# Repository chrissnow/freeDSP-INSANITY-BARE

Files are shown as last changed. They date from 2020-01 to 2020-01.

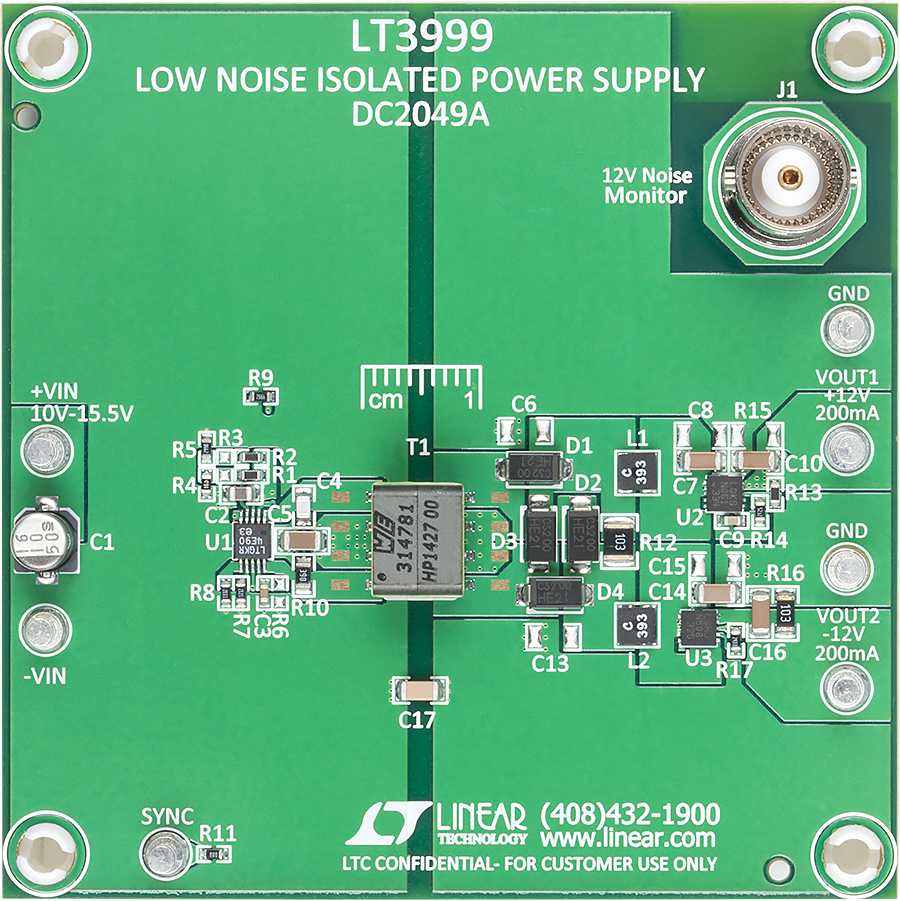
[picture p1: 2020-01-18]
KNOWLEDGE/20170114_LT3999_Example_Circuit_DC2049A_Board.png

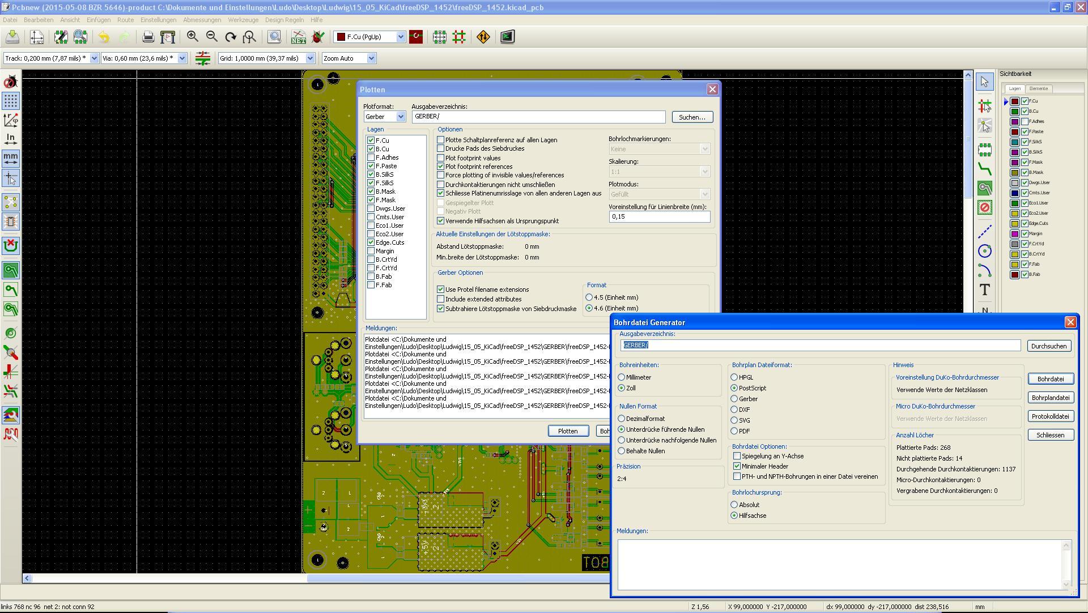
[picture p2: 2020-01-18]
GERBER/GERBER_Settings_Export1.JPG

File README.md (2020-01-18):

# freeDSP INSANITY BARE

BOARD STATUS: WORK IN PROGRESS - DO NOT BUILD!

MAIN COORDINATOR: [sudlud](https://github.com/sudlud), [blauespferd](https://github.com/blauespferd)

Working directory for the modularized freeDSP INSANITY (the big brother of freeDSP classic). (Final board-name still undefined)

LIBRARY:

This project uses the freeDSP-KiCad-Library:
https://github.com/freeDSP/freeDSP-KiCadLibrary.git

The library is included as a submodule. It can be initialized using the following commands:

git submodule init

git submodule update

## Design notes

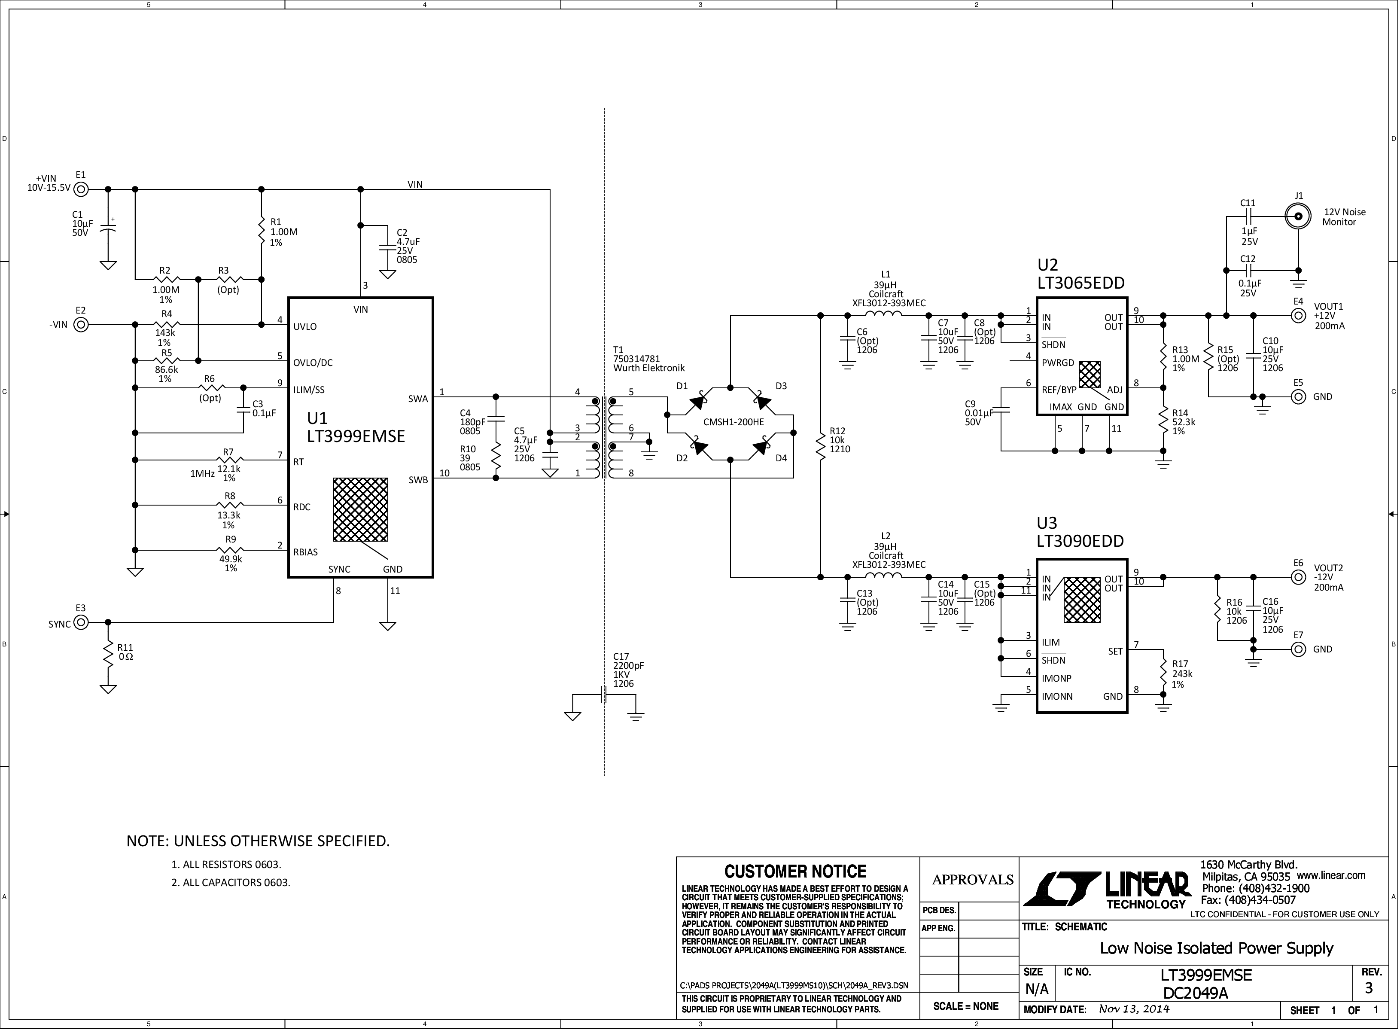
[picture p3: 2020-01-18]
KNOWLEDGE/20170114_LT3999_Example_Circuit_DC2049A.png

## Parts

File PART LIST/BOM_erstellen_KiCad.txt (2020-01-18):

BOM-Export über PCBNEW

-> Datei -> Feritungsdaten erstellen -> BOM-Datei !!! Viel besser als die BOM aus EESCHEMA

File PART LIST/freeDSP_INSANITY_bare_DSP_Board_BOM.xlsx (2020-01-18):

ID | Bezeichner | Geh√§use | St√ºckzahl | Bezeichnung | Anbieter und Referenz | Reichelt.de | DigiKey.com | Conrad.de
1 | C4,C1,C133,C130,C129,C121,C119,C110,C109,C105,C100,C93,C91 | C_0805 | 13 | 10u |  | X5R-G0805 10/16
2 | FB5,FB4,FB3,FB2 | R_0603 | 4 | BLM18PG471SN1 |  | BLM18PG 471
3 | C7,C6,C5,C3,C2,C134,C132,C131,C128,C127,C118,C117,C114,C113,C112,C111,C107,C103,C101,C98,C97,C95,C92,C88 | C_0603 | 24 | 100n |  | X7R-G0603 100N
4 | U1 | TSSOP-24_4.4x7.8mm_P0.65mm | 1 | W232-10-fdsp_digital |  |  | 428-2893-5-ND
5 | R6,R5,R4,R3,R2,R1 | R_0603_Solderjumper_Closed | 6 | Jumper_NC_Small
6 | REF**,REF**,REF**,REF** | MountingHole_3.2mm_M3 | 4 | MountingHole_3.2mm_M3
7 | P5,P4,P3,P2,P1,P33,P30,P27 | IDC_Header_Straight_16pins | 8 | CONN_02X08 |  | WSL 16G
8 | U16 | SOIJ-8_5.3x5.3mm_Pitch1.27mm | 1 | 25AA1024 |  |  | 25AA1024-I/SM-ND
9 | P24 | IDC_Header_Straight_10pins | 1 | CONN_02X05 |  | WSL 10G
10 | P28 | FC684205T_R | 1 | FC684205R |  |  |  | 457611
11 | P25 | FC684205T_R | 1 | FC684205T
12 | U17 | CB3LV-3C-24M5760 | 1 | CB3LV-3C-24M5760 |  |  | CTX1269CT-ND
13 | U13 | SOT23-6_1.7x3.0mm_Pitch0.95mm | 1 | LM2842Y |  |  | LM2842YMK-ADJL/NOPBCT-ND
14 | U12 | LFCSP-72_10x10mm_Pitch0.5mm_ADAU1452 | 1 | ADAU1452 |  |  | ADAU1452WBCPZ-ND
15 | SW1 | SW_SPST_PTS645 | 1 | SW_PUSH_SMALL |  | TASTER 9315
16 | R163,R161,R159,R156,R123,R121 | R_0603 | 6 | 10k |  | SMD-0603 10K
17 | R162,R160,R148,R147,R132,R122 | R_0603 | 6 | 1k |  | SMD-0603 1,0K
18 | R158,R157 | R_0603_Solderjumper_Open | 2 | 10k
19 | R155,R154 | R_0603_Solderjumper_Open | 2 | 0
20 | R151 | R_0603 | 1 | 3.4k |  | RND 0603 1 3,4K
21 | R149 | R_0603 | 1 | 1.02k |  |  | 311-1.02KHRCT-ND
22 | R146,R145,R144,R143,R142,R141,R140,R139,R138,R137,R136,R135,R131,R130,R129,R128,R127,R126,R125,R124 | R_0603 | 20 | 33 |  | SMD-0603 33
23 | R134 | R_0603 | 1 | 50 |  | SMD-0603 47
24 | R133 | R_0603 | 1 | 4.3k |  | RND 0603 1 4,3K
25 | Q1 | D-Pak_TO252AA | 1 | STD2805T4 |  |  | 497-7465-1-ND
26 | P42 | Pin_Header_Straight_2x08 | 1 | CONN_02X08 |  | MPE 087-2-016
27 | P41 | Pin_Header_Straight_2x06 | 1 | CONN_02X06 |  | MPE 087-2-016 (gekürzt)
28 | P40,P39,P38,P37,P36,P35,P31,P26,P23,P18,P17,P15 | Measurement_Point_Round-SMD-Pad_Small | 12 | TST
29 | P34 | Pin_Header_Straight_1x08 | 1 | CONN_01X08 |  | MPE 087-1-008
30 | P16 | RIACON101-2 | 1 | CONN_01X02 |  | AKL 101-02
31 | L1 | Choke_SMD_6.0x5.8 | 1 | 47u |  | L-PIS2408 47µ
32 | JP1 | Pin_Header_Straight_1x02 | 1 | Jumper_NO_Small |  | MPE 087-1-002
33 | FB1 | R_1206 | 1 | Ferrite bead |  |  | 240-2405-1-ND
34 | F1 | R_1206 | 1 | 0ZCJ0050AF2E |  |  | 507-1803-1-ND
35 | D6,D2 | SMA | 2 | B150 |  |  | B150-FDICT-ND
36 | D5 | SMA | 1 | SMAJ28A |  | SMAJ 15A VIS
37 | D4,D3 | R_0603 | 2 | green |  | SMD-LED 0603 GN
38 | C115 | C_0805 | 1 | 150n |  | X7R 0805FCF 150N
39 | C104 | CP_Elec_10x10.5 | 1 | 100u |  | VF 100/63 K-G
40 | C102,C99,C96,C94 | C_0603 | 4 | 1u |  | X5R-G0603 1,0/25
41 | C90 | C_0603 | 1 | 150p |  | NPO-G0603 150P
42 | C89 | C_0805 | 1 | 5.6n |  | X7R 0805 CF 5,6N

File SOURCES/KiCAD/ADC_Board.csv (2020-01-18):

ID | Bezeichner | Gehäuse | Stückzahl | Bezeichnung | Anbieter und Referenz
1 | C33,C37,C38,C39,C40,C41,C42,C43,C55,C56,C57,C58,C59,C60,C61,C62 | C_Radial_D5_L11_P2.5 | 16 | 10u
2 | C44,C64 | C_0603 | 2 | 1u
3 | C45,C46,C54,C68,C69,C76,C81,C82,C83,C86,C91,C92 | C_0603 | 12 | 100n
4 | C47,C53,C70,C75,C84 | C_0805 | 5 | 10u
5 | C48,C49,C50,C51,C71,C72,C73,C74 | C_1206 | 8 | 1.5n
6 | C77,C78,C79,C80,C87,C88,C89,C90 | C_Radial_D10_L16_P5 | 8 | 22u
7 | D8 | SOT-23 | 1 | LM4040DYM3-2.5
8 | J1,J2 | AUDIO_JACK_STEREO_12PIN_FCR1117 | 2 | AUDIO_JACK_STEREO_12PIN_FCR1117
9 | P4,P5,P6,P7,P14,P15 | Measurement_Point_Round-SMD-Pad_Small | 6 | TST
10 | R37,R38,R39,R40,R41,R42,R43,R44,R57,R58,R59,R60,R61,R62,R63,R64 | R_0603 | 16 | 330
11 | R45,R47,R52,R54,R55,R65,R67,R72,R74,R75 | R_0603_Solderjumper_Open | 10 | Jumper_NO_Small
12 | R46,R48,R51,R53,R56,R66,R68,R71,R73,R76 | R_0603_Solderjumper_Closed | 10 | Jumper_NC_Small
13 | R49,R69,R77,R78,R79,R80,R99,R100,R101,R102,R103 | R_0603 | 11 | 10k
14 | R50,R70 | R_0603 | 2 | 33
15 | R87,R88,R89,R90,R104,R105,R106,R107 | R_0603 | 8 | 8.06k
16 | R91,R92,R93,R94,R95,R96,R97,R98,R108,R109,R110,R112,R113,R114,R115,R116 | R_0603 | 16 | 4.7k
17 | U5,U6 | SSOP-28_5.3x10.2mm_Pitch0.65mm | 2 | AK5384
18 | U7,U8,U11,U12 | TSSOP-16_4.4x5mm_Pitch0.65mm | 4 | OPA4353
19 | U9 | SOIC-8_3.9x4.9mm_Pitch1.27mm | 1 | OPA337

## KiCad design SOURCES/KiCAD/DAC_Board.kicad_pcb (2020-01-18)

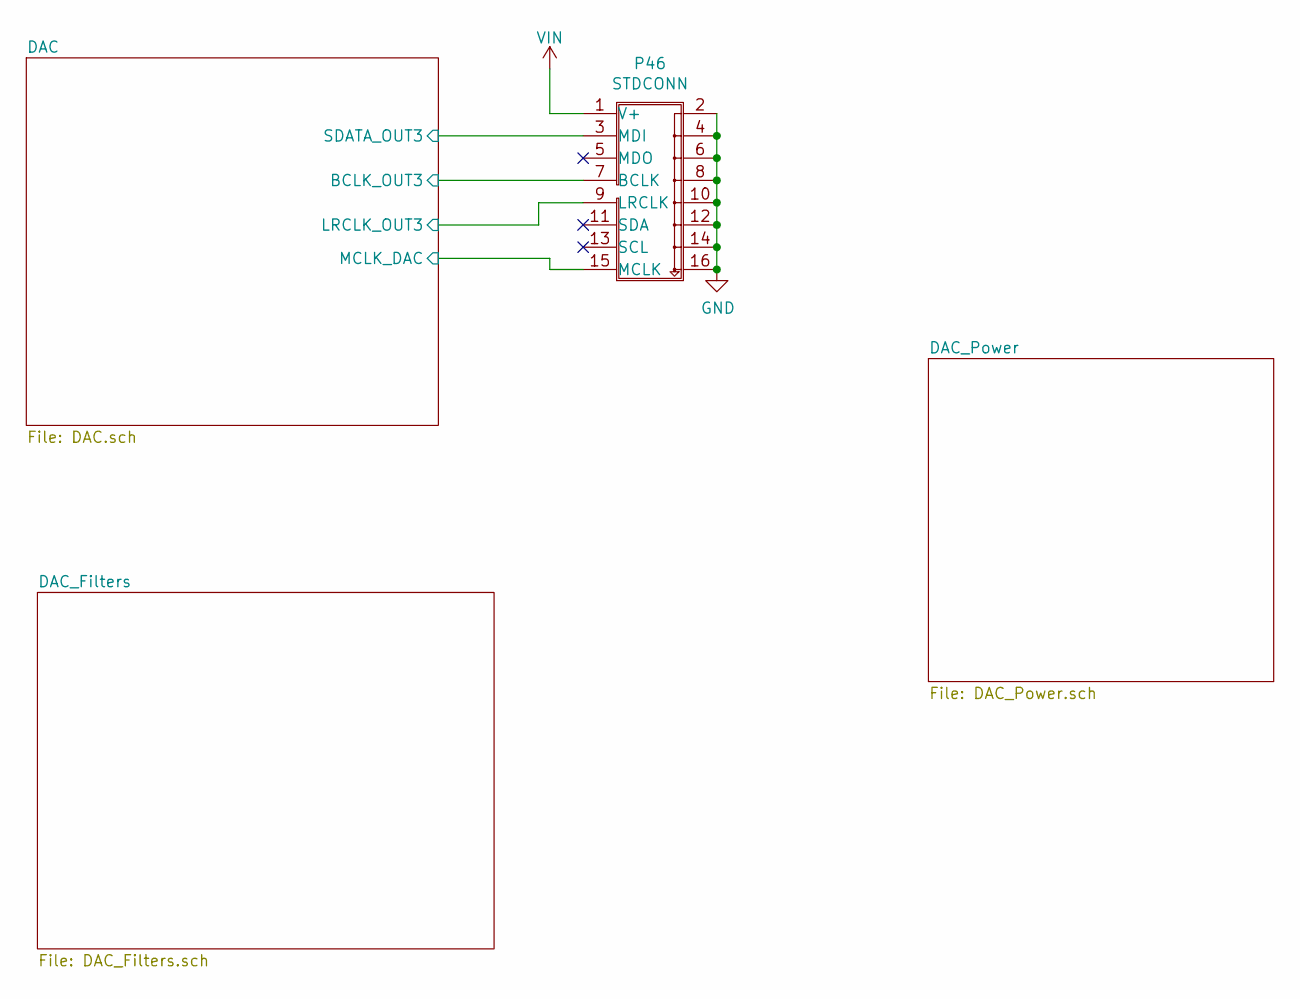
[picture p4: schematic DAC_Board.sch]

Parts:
P46: STDCONN; IDC_Header_Straight_16pins

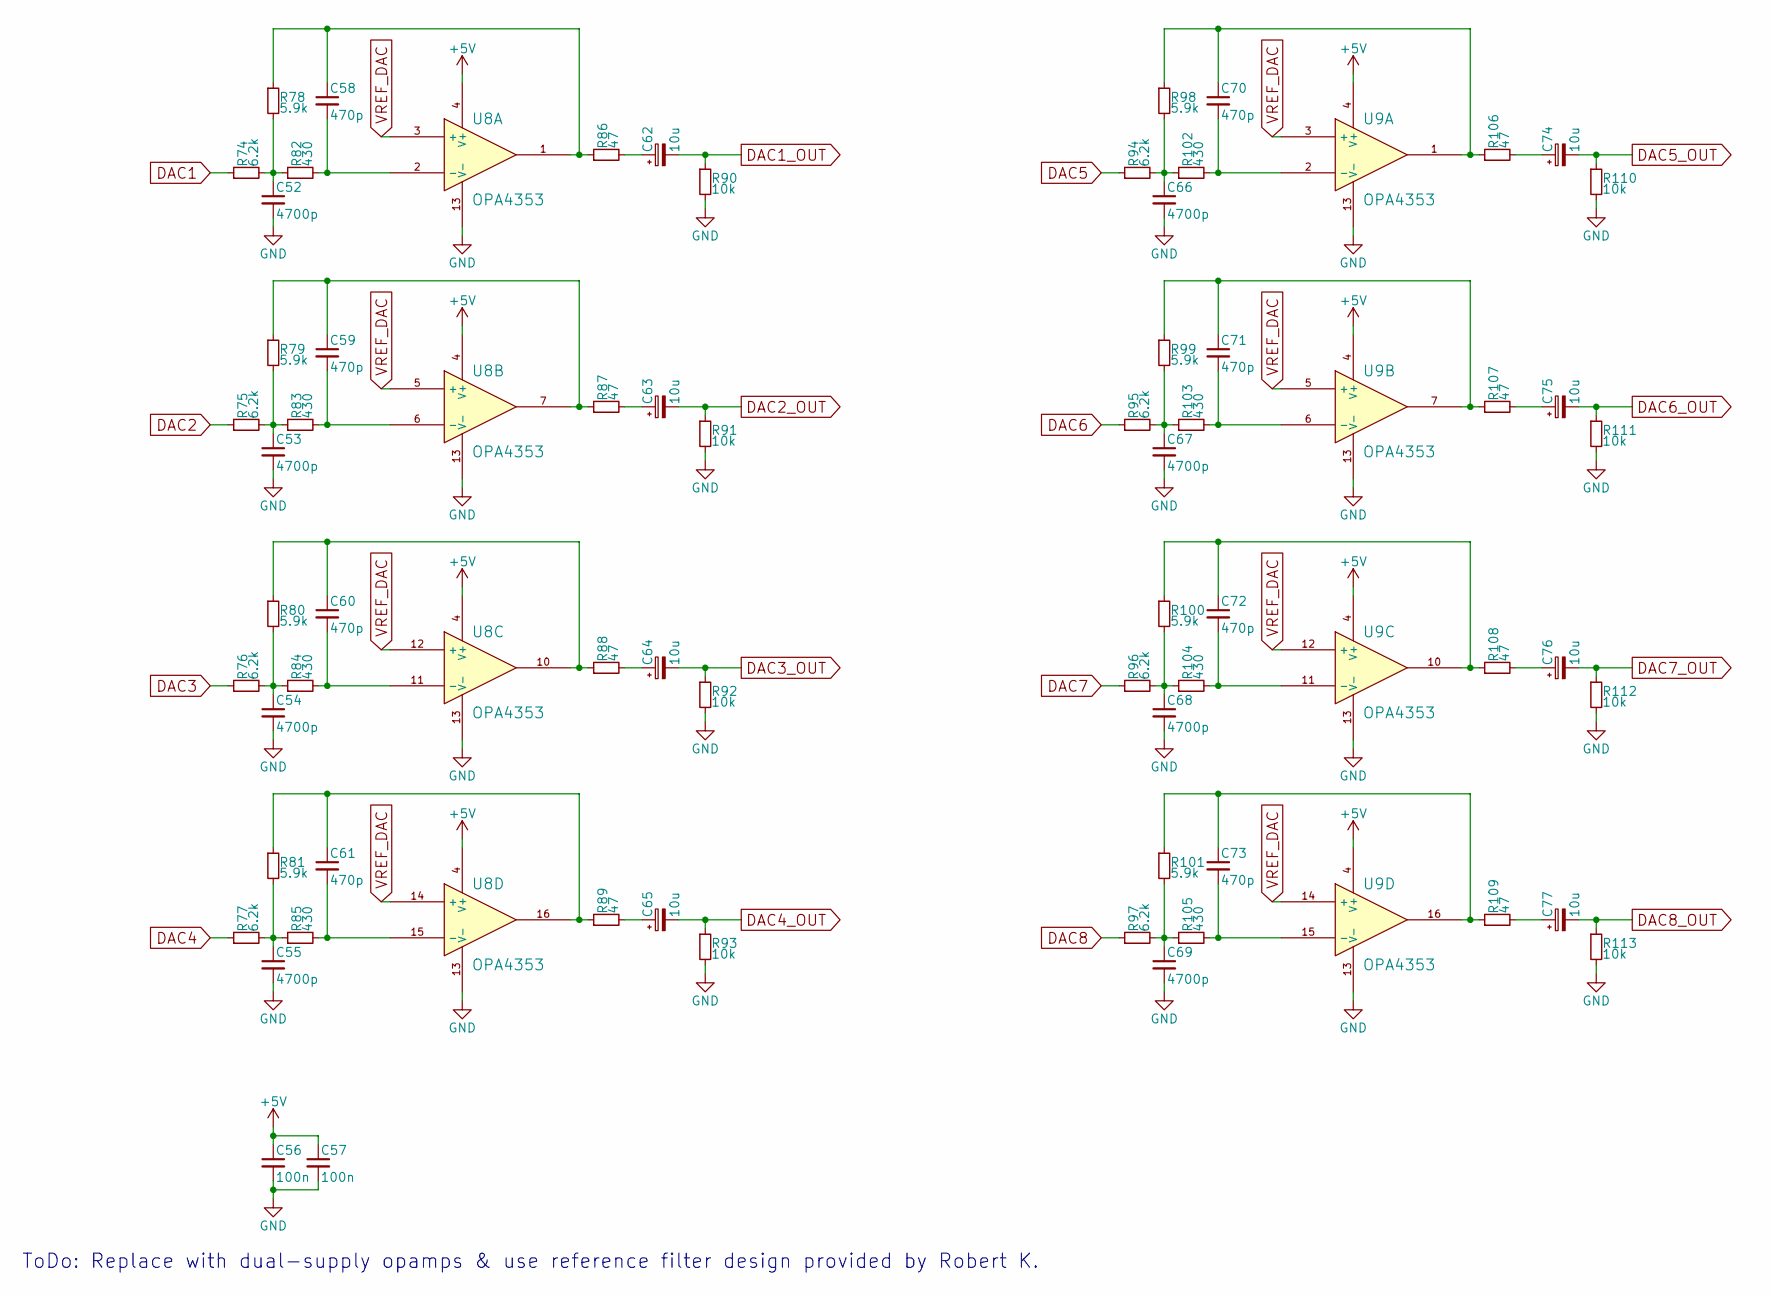
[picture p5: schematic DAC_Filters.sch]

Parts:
C52, C53, C54, C55, C66, C67, C68, C69: 4700p; C_1206
C56, C57: 100n; C_0603
C58, C59, C60, C61, C70, C71, C72, C73: 470p; C_1206
C62, C63, C64, C65, C74, C75, C76, C77: 10u; C_Radial_D10_L16_P5
R74, R75, R76, R77, R94, R95, R96, R97: 6.2k; R_0603
R78, R79, R80, R81, R98, R99, R100, R101: 5.9k; R_0603
R82, R83, R84, R85, R102, R103, R104, R105: 430; R_0603
R86, R87, R88, R89, R106, R107, R108, R109: 47; R_0603
R90, R91, R92, R93, R110, R111, R112, R113: 10k; R_0603
U8, U9: OPA4353; TSSOP-16_4.4x5mm_Pitch0.65mm

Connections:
+5V: C56.1, C57.1, U8.4 (V+), U9.4 (V+); also elsewhere on the board
DAC1: R74.1; also elsewhere on the board
DAC1_OUT: C62.2, R90.1; also elsewhere on the board
DAC2: R75.1; also elsewhere on the board
DAC2_OUT: C63.2, R91.1; also elsewhere on the board
DAC3: R76.1; also elsewhere on the board
DAC3_OUT: C64.2, R92.1; also elsewhere on the board
DAC4: R77.1; also elsewhere on the board
DAC4_OUT: C65.2, R93.1; also elsewhere on the board
DAC5: R94.1; also elsewhere on the board
DAC5_OUT: C74.2, R110.1; also elsewhere on the board
DAC6: R95.1; also elsewhere on the board
DAC6_OUT: C75.2, R111.1; also elsewhere on the board
DAC7: R96.1; also elsewhere on the board
DAC7_OUT: C76.2, R112.1; also elsewhere on the board
DAC8: R97.1; also elsewhere on the board
DAC8_OUT: C77.2, R113.1; also elsewhere on the board
GND: C52.2, C53.2, C54.2, C55.2, C56.2, C57.2, C66.2, C67.2, C68.2, C69.2, R90.2, R91.2, R92.2, R93.2, R110.2, R111.2, R112.2, R113.2, U8.13 (V-), U9.13 (V-); also elsewhere on the board
unnamed: C52.1, R74.2, R78.2, R82.1
unnamed: C53.1, R75.2, R79.2, R83.1
unnamed: C54.1, R76.2, R80.2, R84.1
unnamed: C55.1, R77.2, R81.2, R85.1
unnamed: C58.1, R78.1, R86.1, U8.1
unnamed: C58.2, R82.2, U8.2 (-)
unnamed: C59.1, R79.1, R87.1, U8.7
unnamed: C59.2, R83.2, U8.6 (-)
unnamed: C60.1, R80.1, R88.1, U8.10
unnamed: C60.2, R84.2, U8.11 (-)
unnamed: C61.1, R81.1, R89.1, U8.16
unnamed: C61.2, R85.2, U8.15 (-)
unnamed: C62.1, R86.2
unnamed: C63.1, R87.2
unnamed: C64.1, R88.2
unnamed: C65.1, R89.2
unnamed: C66.1, R94.2, R98.2, R102.1
unnamed: C67.1, R95.2, R99.2, R103.1
unnamed: C68.1, R96.2, R100.2, R104.1
unnamed: C69.1, R97.2, R101.2, R105.1
unnamed: C70.1, R98.1, R106.1, U9.1
unnamed: C70.2, R102.2, U9.2 (-)
unnamed: C71.1, R99.1, R107.1, U9.7
unnamed: C71.2, R103.2, U9.6 (-)
unnamed: C72.1, R100.1, R108.1, U9.10
unnamed: C72.2, R104.2, U9.11 (-)
unnamed: C73.1, R101.1, R109.1, U9.16
unnamed: C73.2, R105.2, U9.15 (-)
unnamed: C74.1, R106.2
unnamed: C75.1, R107.2
unnamed: C76.1, R108.2
unnamed: C77.1, R109.2
VREF_DAC: U8.3 (+), U8.5 (+), U8.12 (+), U8.14 (+), U9.3 (+), U9.5 (+), U9.12 (+), U9.14 (+); also elsewhere on the board

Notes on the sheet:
ToDo: Replace with dual-supply opamps & use reference filter design provided by Robert K.

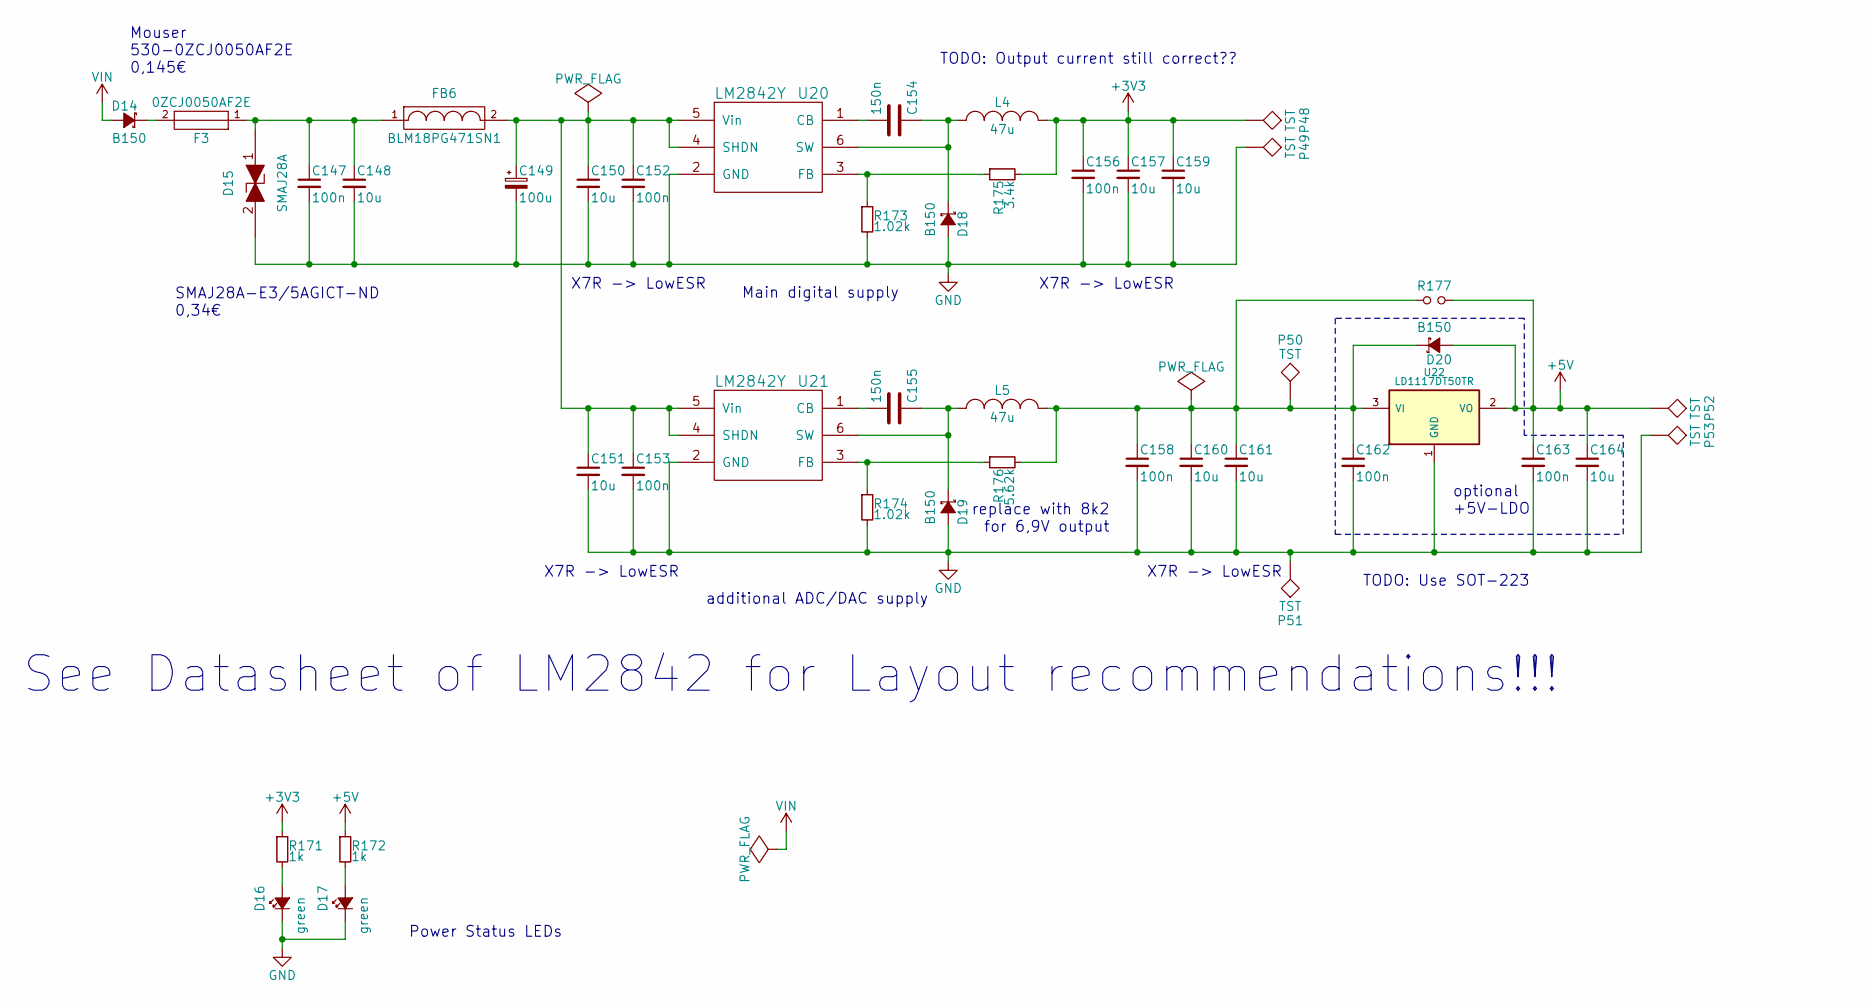
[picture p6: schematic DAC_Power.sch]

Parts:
C147, C152, C153, C156, C158, C162, C163: 100n; C_0603
C148, C150, C151, C157, C159, C160, C161, C164: 10u; C_0805
C149: 100u; CP_Elec_10x10.5
C154, C155: 150n; C_0805
D14, D18, D19, D20: B150; SMA
D15: SMAJ28A; SMA; Digikey_Paro_No SMAJ28A-E3/5AGICT-ND
D16, D17: green; R_0603
F3: 0ZCJ0050AF2E; R_1206; Mouser_Part_No 530-0ZCJ0050AF2E
FB6: BLM18PG471SN1; R_0603; Mouser_Part_No 81-BLM18PG471SN1D
L4, L5: 47u; Choke_SMD_6.0x5.8
P48, P49, P50, P51, P52, P53: TST; Measurement_Point_Round-SMD-Pad_Small
R171, R172: 1k; R_0603
R173, R174: 1.02k; R_0603
R175: 3.4k; R_0603
R176: 5.62k; R_0603
R177: Jumper_NO_Small; R_0603_Solderjumper_Open
U20, U21: LM2842Y; SOT23-6_1.7x3.0mm_Pitch0.95mm
U22: LD1117DT50TR; SOT-223

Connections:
+3V3: C156.1, C157.1, C159.1, L4.2, P48.1, R171.1, R175.2; also elsewhere on the board
+5V: C163.1, C164.1, D20.2 (A), P52.1, R172.1, R177.2, U22.2 (VO); also elsewhere on the board
GND: C147.2, C148.2, C149.2, C150.2, C151.2, C152.2, C153.2, C156.2, C157.2, C158.2, C159.2, C160.2, C161.2, C162.2, C163.2, C164.2, D15.2, D16.1 (K), D17.1 (K), D18.2 (A), D19.2 (A), P49.1, P51.1, P53.1, R173.2, R174.2, U20.2 (GND), U21.2 (GND), U22.1 (GND); also elsewhere on the board
unnamed: C147.1, C148.1, D15.1, F3.1, FB6.1
unnamed: C149.1, C150.1, C151.1, C152.1, C153.1, FB6.2, U20.4 (SHDN), U20.5 (Vin), U21.4 (SHDN), U21.5 (Vin)
unnamed: C154.1, D18.1 (K), L4.1, U20.6 (SW)
unnamed: C154.2, U20.1 (CB)
unnamed: C155.1, D19.1 (K), L5.1, U21.6 (SW)
unnamed: C155.2, U21.1 (CB)
unnamed: C158.1, C160.1, C161.1, C162.1, D20.1 (K), L5.2, P50.1, R176.2, R177.1, U22.3 (VI)
unnamed: D14.1 (K), F3.2
unnamed: D16.2 (A), R171.2
unnamed: D17.2 (A), R172.2
unnamed: R173.1, R175.1, U20.3 (FB)
unnamed: R174.1, R176.1, U21.3 (FB)
VIN: D14.2 (A); also elsewhere on the board

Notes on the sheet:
Power Status LEDs
Main digital supply
additional ADC/DAC supply
X7R -> LowESR
See Datasheet of LM2842 for Layout recommendations!!!
replace with 8k2 for 6,9V output
optional +5V-LDO
Mouser 530-0ZCJ0050AF2E 0,145€
TODO: Use SOT-223
TODO: Output current still correct??
SMAJ28A-E3/5AGICT-ND 0,34€

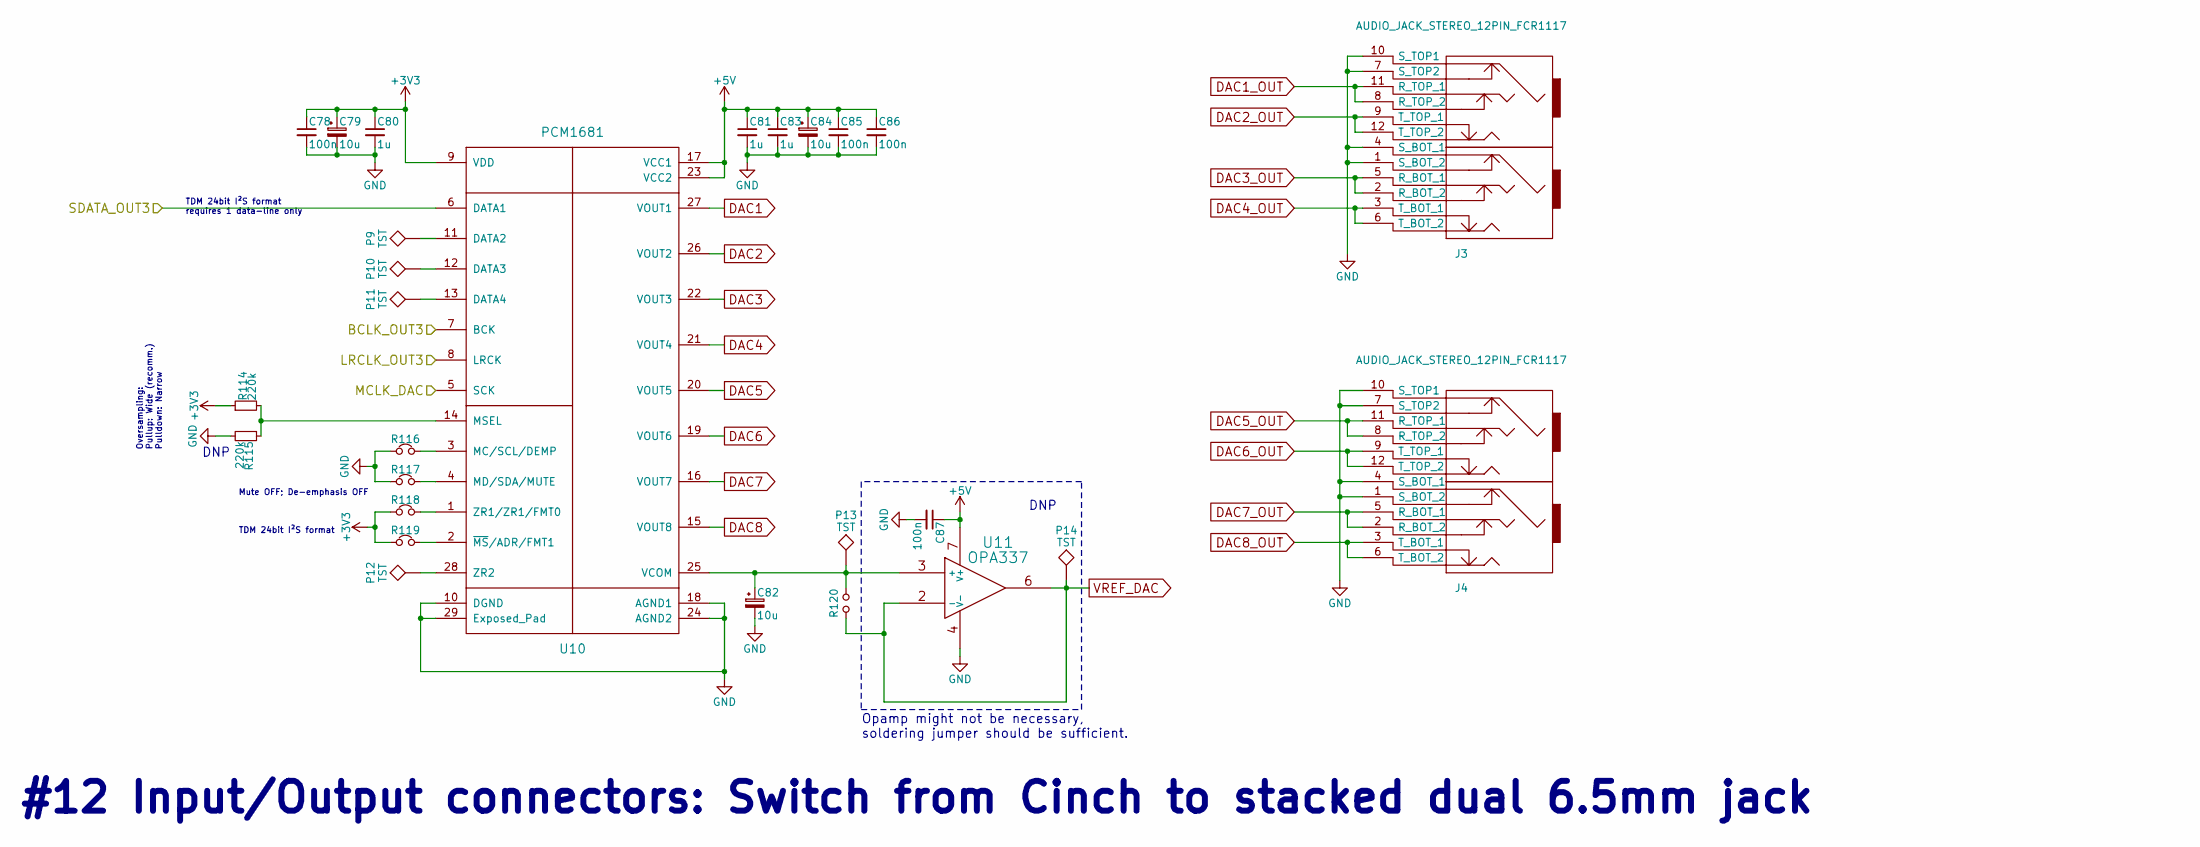
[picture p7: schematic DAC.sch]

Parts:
C78, C85, C86, C87: 100n; C_0603
C79, C82, C84: 10u; C_0805
C80, C81, C83: 1u; C_0603
J3, J4: AUDIO_JACK_STEREO_12PIN_FCR1117
P9, P10, P11, P12, P13, P14: TST; Measurement_Point_Round-SMD-Pad_Small
R114, R115: 220k; R_0603
R116, R117, R118, R119: Jumper_NC_Small; R_0603_Solderjumper_Closed
R120: Jumper_NO_Small; R_0603_Solderjumper_Open
U10: PCM1681; TSSOP-28_10x5mm_Pitch0.65mm_PCM1681
U11: OPA337; SOIC-8_3.9x4.9mm_Pitch1.27mm

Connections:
+3V3: C78.1, C79.1, C80.1, R114.1, R118.1, R119.1, U10.9 (VDD); also elsewhere on the board
+5V: C81.1, C83.1, C84.1, C85.1, C86.1, C87.1, U10.17 (VCC1), U10.23 (VCC2), U11.7 (V+); also elsewhere on the board
/DAC/BCLK_OUT3: U10.7 (BCK); also elsewhere on the board
/DAC/LRCLK_OUT3: U10.8 (LRCK); also elsewhere on the board
/DAC/MCLK_DAC: U10.5 (SCK); also elsewhere on the board
/DAC/SDATA_OUT3: U10.6 (DATA1); also elsewhere on the board
DAC1: U10.27 (VOUT1); also elsewhere on the board
DAC1_OUT: J3.8 (R_TOP_2), J3.11 (R_TOP_1); also elsewhere on the board
DAC2: U10.26 (VOUT2); also elsewhere on the board
DAC2_OUT: J3.9 (T_TOP_1), J3.12 (T_TOP_2); also elsewhere on the board
DAC3: U10.22 (VOUT3); also elsewhere on the board
DAC3_OUT: J3.2 (R_BOT_2), J3.5 (R_BOT_1); also elsewhere on the board
DAC4: U10.21 (VOUT4); also elsewhere on the board
DAC4_OUT: J3.3 (T_BOT_1), J3.6 (T_BOT_2); also elsewhere on the board
DAC5: U10.20 (VOUT5); also elsewhere on the board
DAC5_OUT: J4.8 (R_TOP_2), J4.11 (R_TOP_1); also elsewhere on the board
DAC6: U10.19 (VOUT6); also elsewhere on the board
DAC6_OUT: J4.9 (T_TOP_1), J4.12 (T_TOP_2); also elsewhere on the board
DAC7: U10.16 (VOUT7); also elsewhere on the board
DAC7_OUT: J4.2 (R_BOT_2), J4.5 (R_BOT_1); also elsewhere on the board
DAC8: U10.15 (VOUT8); also elsewhere on the board
DAC8_OUT: J4.3 (T_BOT_1), J4.6 (T_BOT_2); also elsewhere on the board
GND: C78.2, C79.2, C80.2, C81.2, C82.2, C83.2, C84.2, C85.2, C86.2, C87.2, J3.1 (S_BOT_2), J3.4 (S_BOT_1), J3.7 (S_TOP2), J3.10 (S_TOP1), J4.1 (S_BOT_2), J4.4 (S_BOT_1), J4.7 (S_TOP2), J4.10 (S_TOP1), R115.2, R116.1, R117.1, U10.10 (DGND), U10.18 (AGND1), U10.24 (AGND2), U10.29 (Exposed_Pad), U11.4 (V-); also elsewhere on the board
unnamed: C82.1, P13.1, R120.2, U10.25 (VCOM), U11.3 (+)
unnamed: P9.1, U10.11 (DATA2)
unnamed: P10.1, U10.12 (DATA3)
unnamed: P11.1, U10.13 (DATA4)
unnamed: P12.1, U10.28 (ZR2)
unnamed: R114.2, R115.1, U10.14 (MSEL)
unnamed: R116.2, U10.3 (MC/SCL/DEMP)
unnamed: R117.2, U10.4 (MD/SDA/MUTE)
unnamed: R118.2, U10.1 (ZR1/ZR1/FMT0)
unnamed: R119.2, U10.2 (~MS~/ADR/FMT1)
VREF_DAC: P14.1, R120.1, U11.2 (-), U11.6; also elsewhere on the board

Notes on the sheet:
DNP
TDM 24bit I²S format
Mute OFF; De-emphasis OFF
TDM 24bit I²S format requires 1 data-line only
Opamp might not be necessary, soldering jumper should be sufficient.
#12 Input/Output connectors: Switch from Cinch to stacked dual 6.5mm jack
Oversampling: Pullup: Wide (recomm.) Pulldown: Narrow

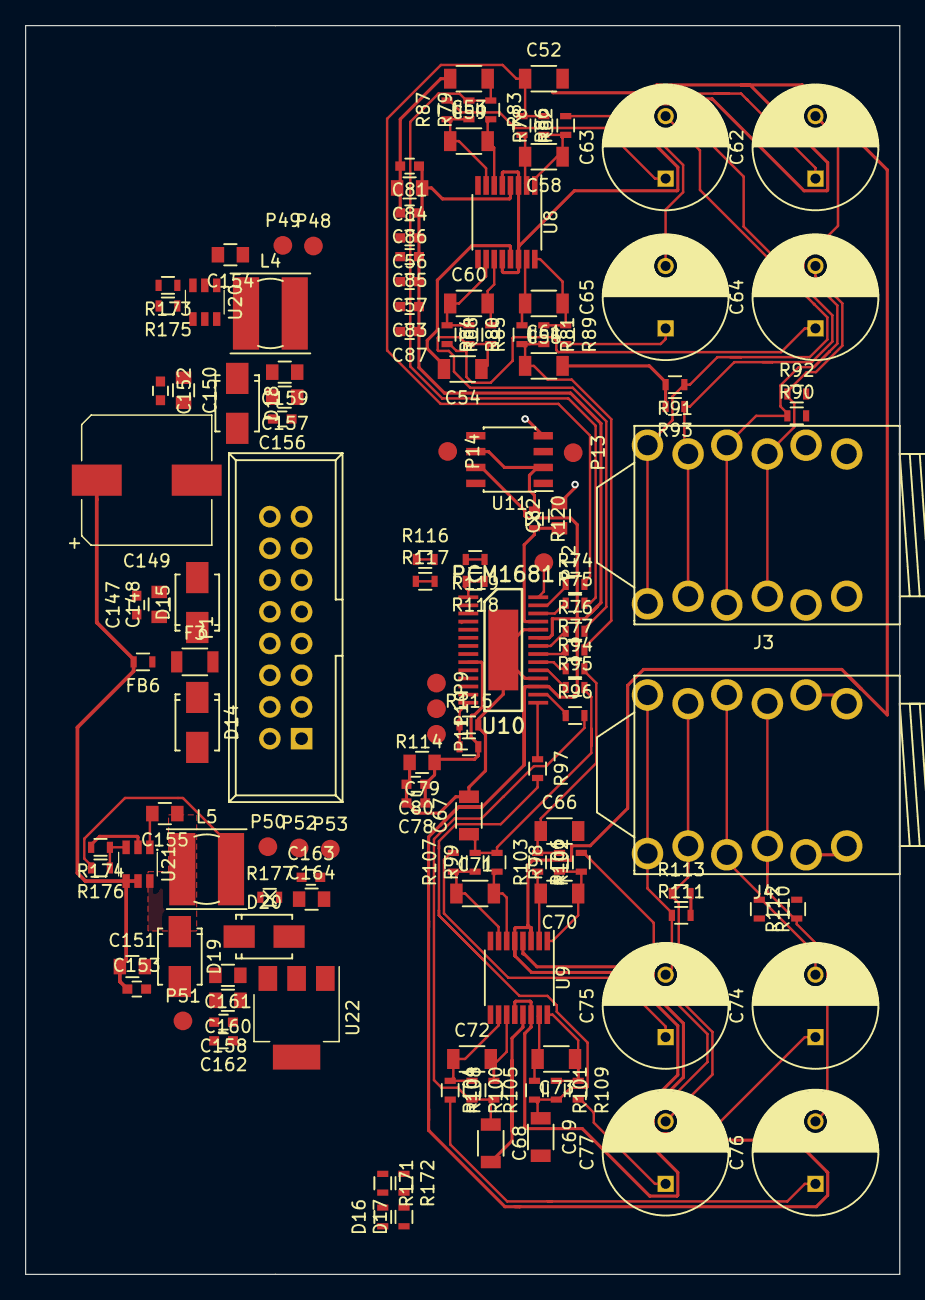
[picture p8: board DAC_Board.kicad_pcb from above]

Board: 2 copper layers, 70.0 x 100.0 mm, 141 parts (0 on the bottom side), 79 nets.

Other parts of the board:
P1: STDCONN; IDC_Header_Straight_16pins

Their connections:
/DAC/BCLK_OUT3: P1.7; also elsewhere on the board
/DAC/LRCLK_OUT3: P1.9; also elsewhere on the board
/DAC/MCLK_DAC: P1.15; also elsewhere on the board
/DAC/SDATA_OUT3: P1.3; also elsewhere on the board
GND: P1.2, P1.4, P1.6, P1.8, P1.10, P1.12, P1.14, P1.16; also elsewhere on the board
VIN: P1.1; also elsewhere on the board

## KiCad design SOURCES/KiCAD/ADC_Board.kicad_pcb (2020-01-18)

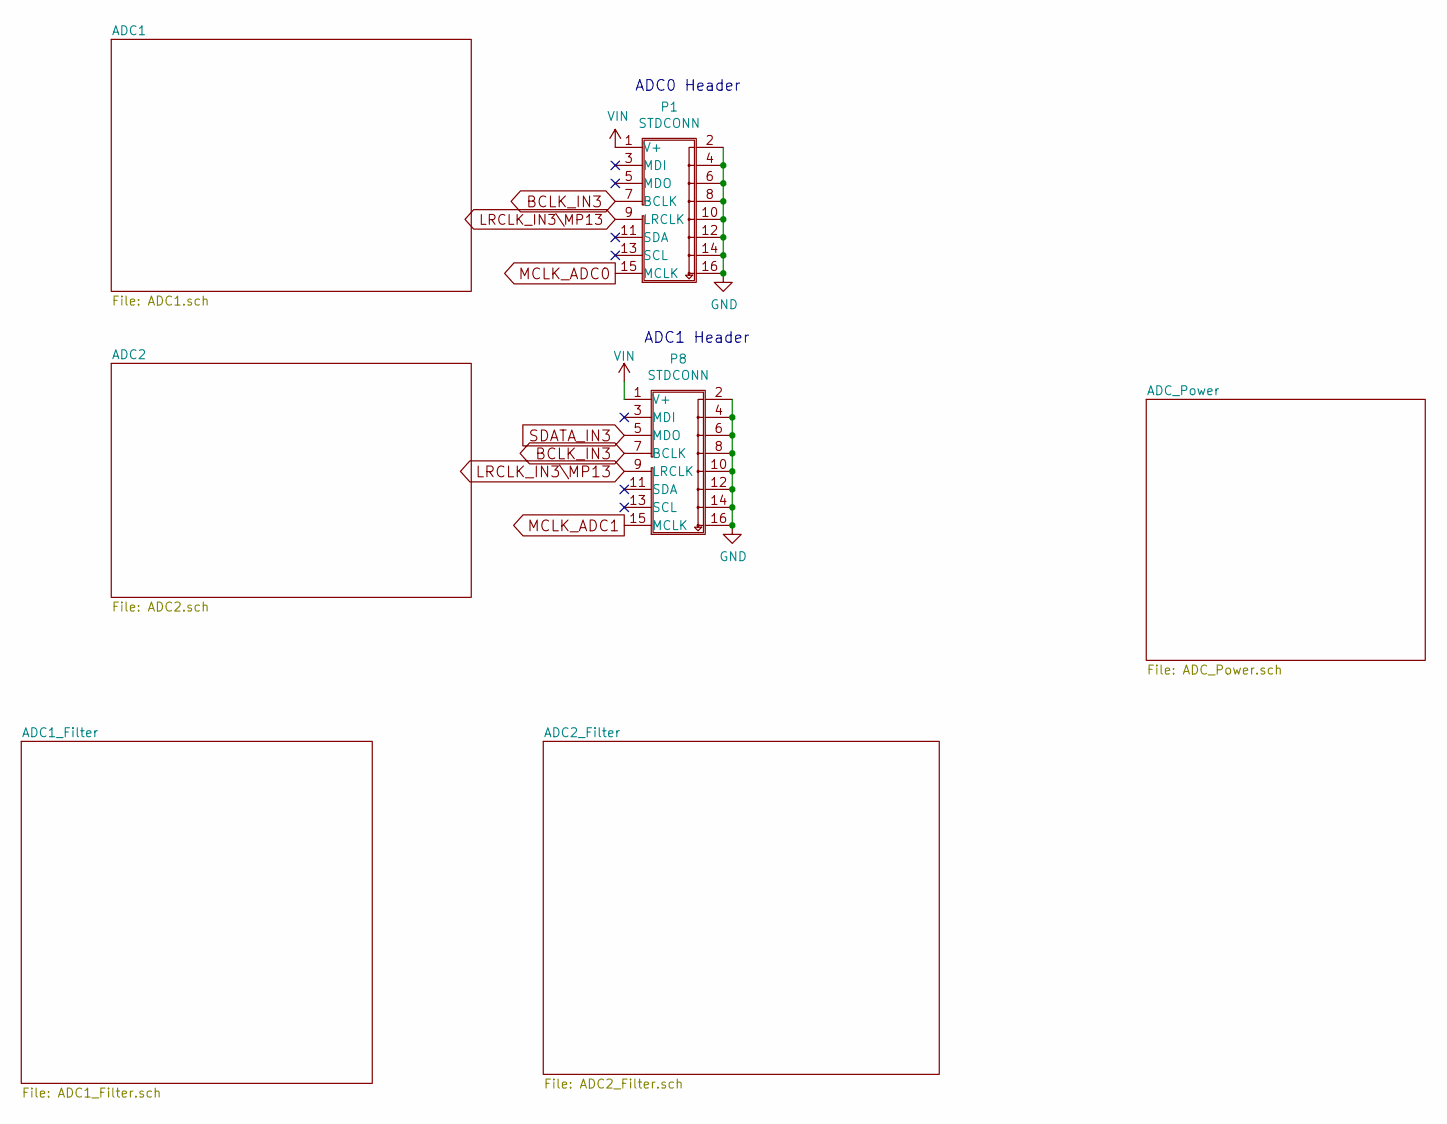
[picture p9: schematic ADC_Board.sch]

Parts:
P1, P8: STDCONN; IDC_Header_Straight_16pins

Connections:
BCLK_IN3: P1.7 (BCLK), P8.7 (BCLK); also elsewhere on the board
GND: P1.2 (GND), P1.4 (GND), P1.6 (GND), P1.8 (GND), P1.10 (GND), P1.12 (GND), P1.14 (GND), P1.16 (GND), P8.2 (GND), P8.4 (GND), P8.6 (GND), P8.8 (GND), P8.10 (GND), P8.12 (GND), P8.14 (GND), P8.16 (GND); also elsewhere on the board
LRCLK_IN3\MP13: P1.9 (LRCLK), P8.9 (LRCLK); also elsewhere on the board
MCLK_ADC0: P1.15 (MCLK); also elsewhere on the board
MCLK_ADC1: P8.15 (MCLK); also elsewhere on the board
SDATA_IN3: P8.5 (MDO); also elsewhere on the board
VIN: P1.1 (V+), P8.1 (V+); also elsewhere on the board

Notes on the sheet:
ADC0 Header
ADC1 Header

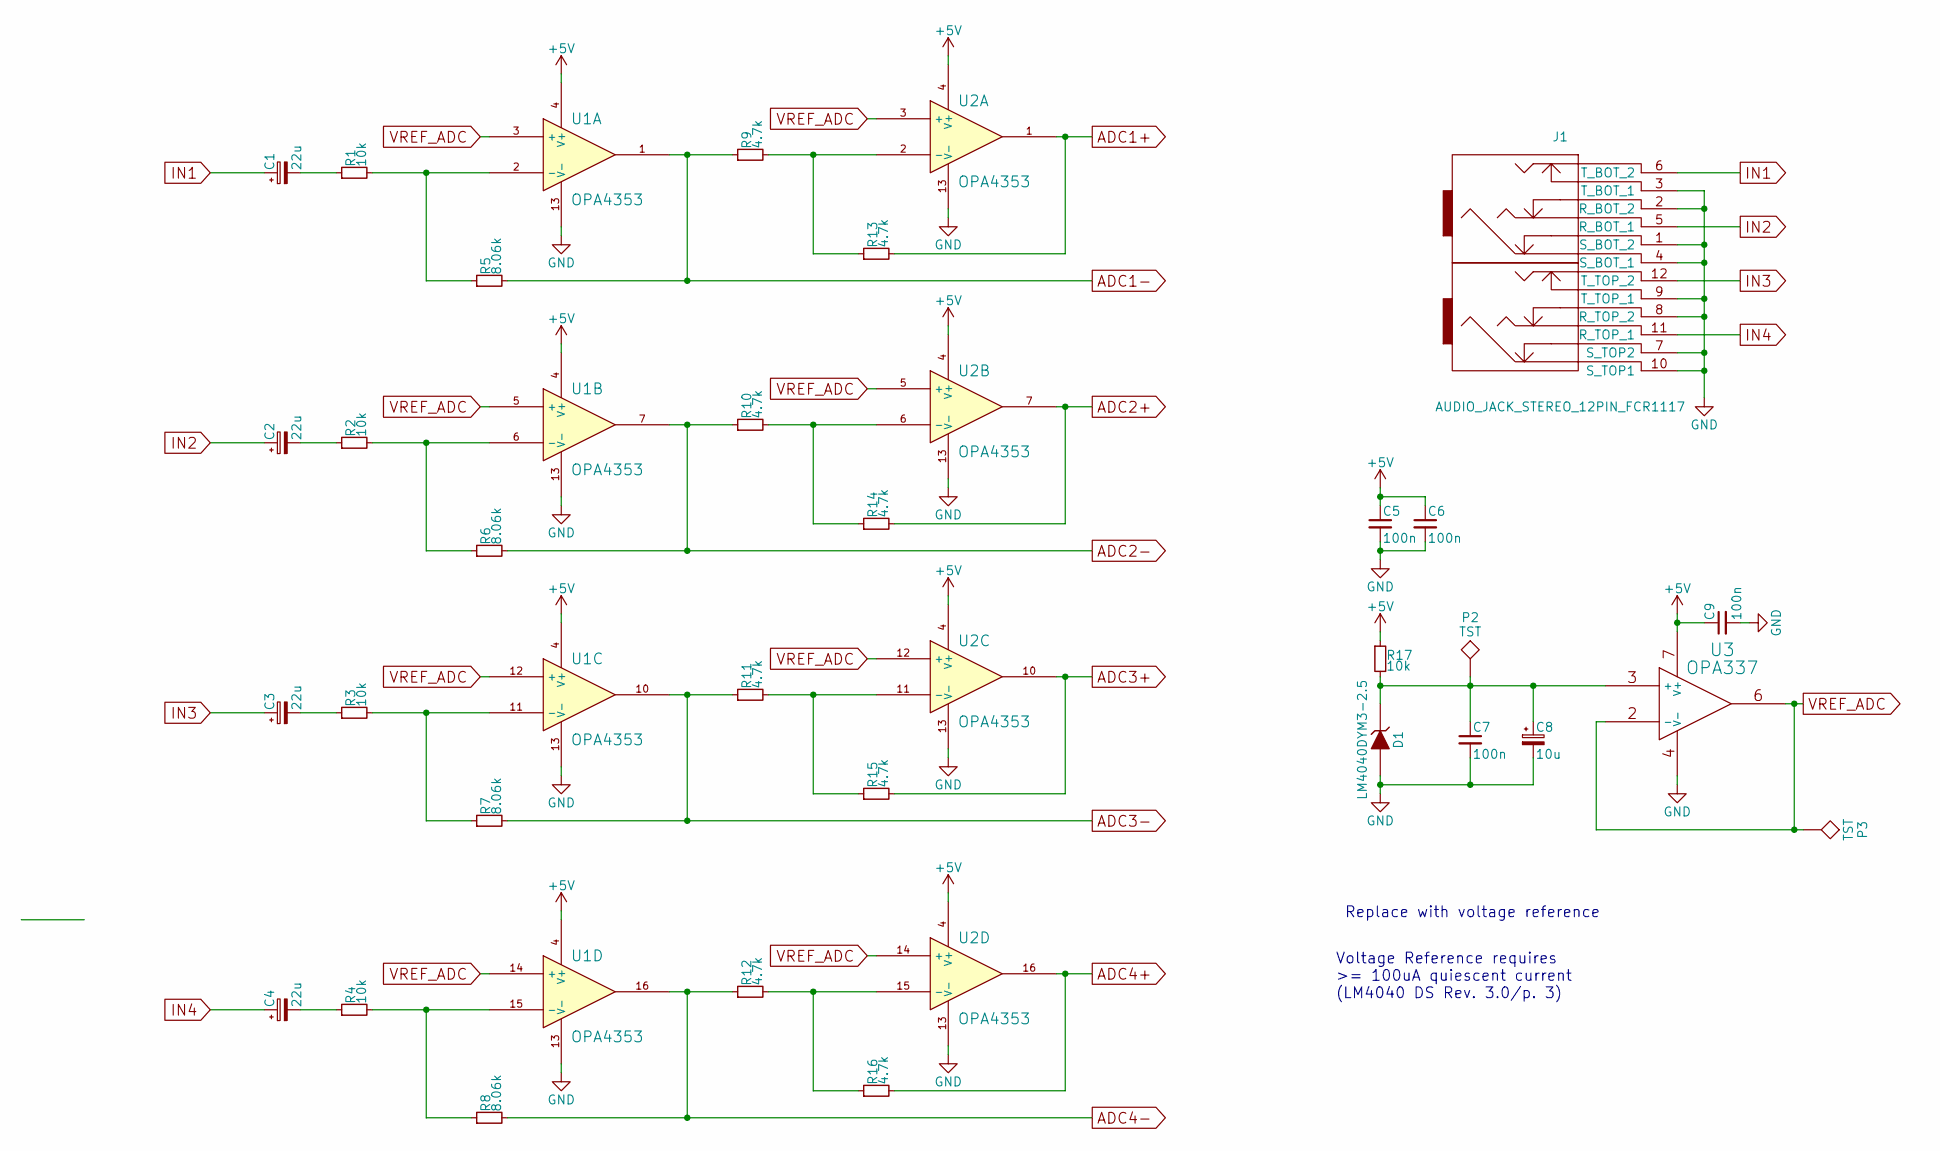
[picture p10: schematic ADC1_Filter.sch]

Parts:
C1, C2, C3, C4: 22u; C_Radial_D10_L16_P5
C5, C6, C7, C9: 100n; C_0603
C8: 10u; C_0805
D1: LM4040DYM3-2.5; SOT-23
J1: AUDIO_JACK_STEREO_12PIN_FCR1117
P2, P3: TST; Measurement_Point_Round-SMD-Pad_Small
R1, R2, R3, R4, R17: 10k; R_0603
R5, R6, R7, R8: 8.06k; R_0603
R9, R10, R11, R12, R13, R14, R15, R16: 4.7k; R_0603
U1, U2: OPA4353; TSSOP-16_4.4x5mm_Pitch0.65mm
U3: OPA337; SOIC-8_3.9x4.9mm_Pitch1.27mm

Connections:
+5V: C5.1, C6.1, C9.1, R17.1, U1.4 (V+), U2.4 (V+), U3.7 (V+); also elsewhere on the board
ADC1+: R13.2, U2.1; also elsewhere on the board
ADC1-: R5.2, R9.1, U1.1; also elsewhere on the board
ADC2+: R14.2, U2.7; also elsewhere on the board
ADC2-: R6.2, R10.1, U1.7; also elsewhere on the board
ADC3+: R15.2, U2.10; also elsewhere on the board
ADC3-: R7.2, R11.1, U1.10; also elsewhere on the board
ADC4+: R16.2, U2.16; also elsewhere on the board
ADC4-: R8.2, R12.1, U1.16; also elsewhere on the board
GND: C5.2, C6.2, C7.2, C8.2, C9.2, D1.2 (A), J1.1 (S_BOT_2), J1.2 (R_BOT_2), J1.3 (T_BOT_1), J1.4 (S_BOT_1), J1.7 (S_TOP2), J1.8 (R_TOP_2), J1.9 (T_TOP_1), J1.10 (S_TOP1), U1.13 (V-), U2.13 (V-), U3.4 (V-); also elsewhere on the board
IN1: C1.1, J1.6 (T_BOT_2)
IN2: C2.1, J1.5 (R_BOT_1)
IN3: C3.1, J1.12 (T_TOP_2)
IN4: C4.1, J1.11 (R_TOP_1)
unnamed: C1.2, R1.1
unnamed: C2.2, R2.1
unnamed: C3.2, R3.1
unnamed: C4.2, R4.1
unnamed: C7.1, C8.1, D1.1 (K), P2.1, R17.2, U3.3 (+)
unnamed: R1.2, R5.1, U1.2 (-)
unnamed: R2.2, R6.1, U1.6 (-)
unnamed: R3.2, R7.1, U1.11 (-)
unnamed: R4.2, R8.1, U1.15 (-)
unnamed: R10.2, R14.1, U2.6 (-)
unnamed: R11.2, R15.1, U2.11 (-)
unnamed: R12.2, R16.1, U2.15 (-)
unnamed: R9.2, R13.1, U2.2 (-)
VREF_ADC: P3.1, U1.3 (+), U1.5 (+), U1.12 (+), U1.14 (+), U2.3 (+), U2.5 (+), U2.12 (+), U2.14 (+), U3.2 (-), U3.6; also elsewhere on the board

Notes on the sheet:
Replace with voltage reference
Voltage Reference requires >= 100uA quiescent current (LM4040 DS Rev. 3.0/p. 3)

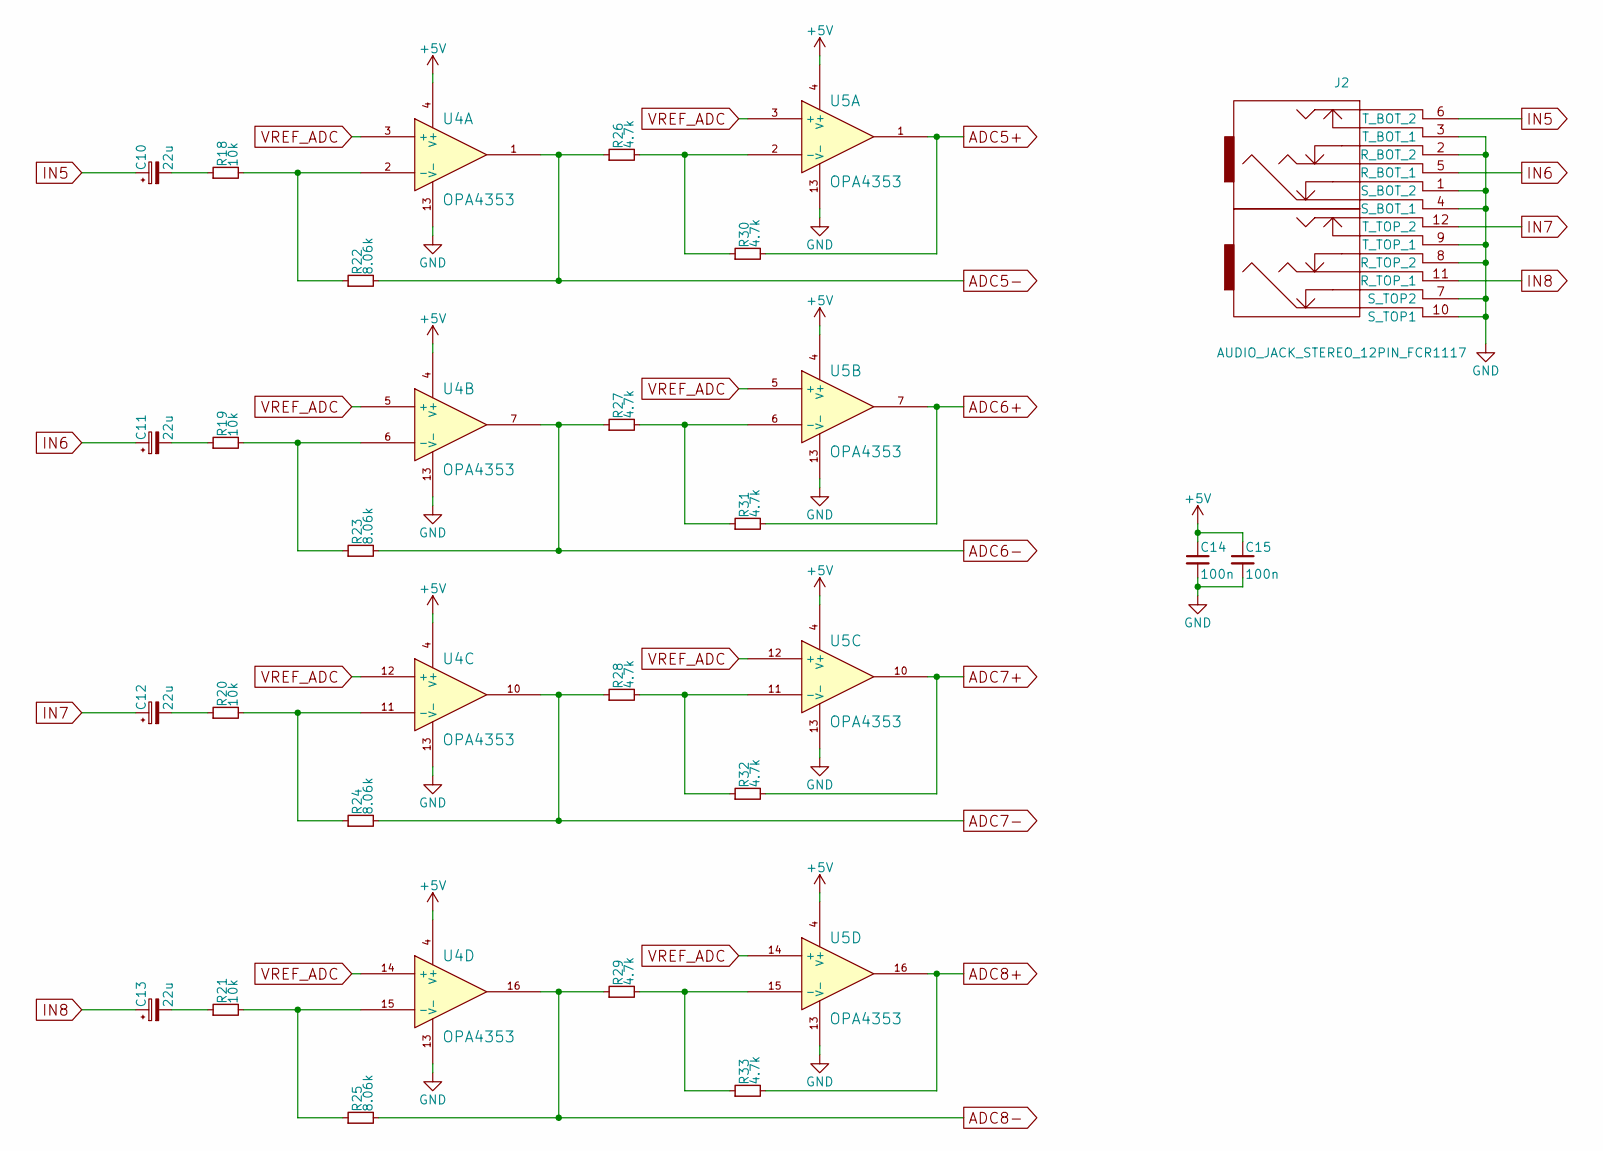
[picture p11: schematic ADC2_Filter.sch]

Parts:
C10, C11, C12, C13: 22u; C_Radial_D10_L16_P5
C14, C15: 100n; C_0603
J2: AUDIO_JACK_STEREO_12PIN_FCR1117
R18, R19, R20, R21: 10k; R_0603
R22, R23, R24, R25: 8.06k; R_0603
R26, R27, R28, R29, R30, R31, R32, R33: 4.7k; R_0603
U4, U5: OPA4353; TSSOP-16_4.4x5mm_Pitch0.65mm

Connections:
+5V: C14.1, C15.1, U4.4 (V+), U5.4 (V+); also elsewhere on the board
ADC5+: R30.2, U5.1; also elsewhere on the board
ADC5-: R22.2, R26.1, U4.1; also elsewhere on the board
ADC6+: R31.2, U5.7; also elsewhere on the board
ADC6-: R23.2, R27.1, U4.7; also elsewhere on the board
ADC7+: R32.2, U5.10; also elsewhere on the board
ADC7-: R24.2, R28.1, U4.10; also elsewhere on the board
ADC8+: R33.2, U5.16; also elsewhere on the board
ADC8-: R25.2, R29.1, U4.16; also elsewhere on the board
GND: C14.2, C15.2, J2.1 (S_BOT_2), J2.2 (R_BOT_2), J2.3 (T_BOT_1), J2.4 (S_BOT_1), J2.7 (S_TOP2), J2.8 (R_TOP_2), J2.9 (T_TOP_1), J2.10 (S_TOP1), U4.13 (V-), U5.13 (V-); also elsewhere on the board
IN5: C10.1, J2.6 (T_BOT_2)
IN6: C11.1, J2.5 (R_BOT_1)
IN7: C12.1, J2.12 (T_TOP_2)
IN8: C13.1, J2.11 (R_TOP_1)
unnamed: C10.2, R18.1
unnamed: C11.2, R19.1
unnamed: C12.2, R20.1
unnamed: C13.2, R21.1
unnamed: R18.2, R22.1, U4.2 (-)
unnamed: R19.2, R23.1, U4.6 (-)
unnamed: R20.2, R24.1, U4.11 (-)
unnamed: R21.2, R25.1, U4.15 (-)
unnamed: R26.2, R30.1, U5.2 (-)
unnamed: R27.2, R31.1, U5.6 (-)
unnamed: R28.2, R32.1, U5.11 (-)
unnamed: R29.2, R33.1, U5.15 (-)
VREF_ADC: U4.3 (+), U4.5 (+), U4.12 (+), U4.14 (+), U5.3 (+), U5.5 (+), U5.12 (+), U5.14 (+); also elsewhere on the board

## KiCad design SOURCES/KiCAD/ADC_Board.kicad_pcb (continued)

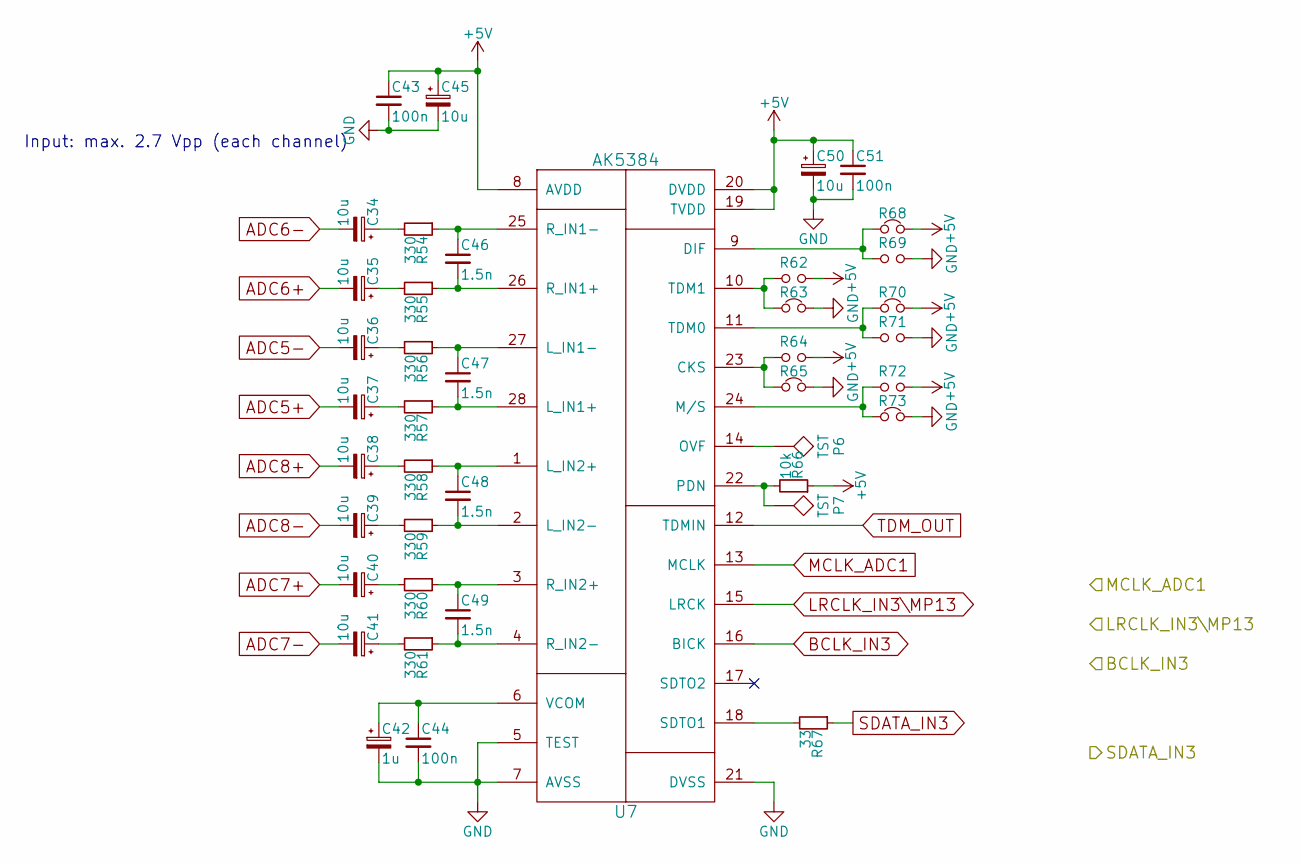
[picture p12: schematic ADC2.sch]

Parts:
C34, C35, C36, C37, C38, C39, C40, C41: 10u; C_Radial_D5_L11_P2.5
C42: 1u; C_0603
C43, C44, C51: 100n; C_0603
C45, C50: 10u; C_0805
C46, C47, C48, C49: 1.5n; C_1206
P6, P7: TST; Measurement_Point_Round-SMD-Pad_Small
R54, R55, R56, R57, R58, R59, R60, R61: 330; R_0603
R62, R64, R69, R71, R72: Jumper_NO_Small; R_0603_Solderjumper_Open
R63, R65, R68, R70, R73: Jumper_NC_Small; R_0603_Solderjumper_Closed
R66: 10k; R_0603
R67: 33; R_0603
U7: AK5384; SSOP-28_5.3x10.2mm_Pitch0.65mm

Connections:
+5V: C43.1, C45.1, C50.1, C51.1, R62.1, R64.1, R66.1, R68.1, R70.1, R72.1, U7.8 (AVDD), U7.19 (TVDD), U7.20 (DVDD); also elsewhere on the board
ADC5+: C37.2; also elsewhere on the board
ADC5-: C36.2; also elsewhere on the board
ADC6+: C35.2; also elsewhere on the board
ADC6-: C34.2; also elsewhere on the board
ADC7+: C40.2; also elsewhere on the board
ADC7-: C41.2; also elsewhere on the board
ADC8+: C38.2; also elsewhere on the board
ADC8-: C39.2; also elsewhere on the board
BCLK_IN3: U7.16 (BICK); also elsewhere on the board
GND: C42.2, C43.2, C44.2, C45.2, C50.2, C51.2, R63.2, R65.2, R69.2, R71.2, R73.2, U7.5 (TEST), U7.7 (AVSS), U7.21 (DVSS); also elsewhere on the board
LRCLK_IN3\MP13: U7.15 (LRCK); also elsewhere on the board
MCLK_ADC1: U7.13 (MCLK); also elsewhere on the board
unnamed: C34.1, R54.2
unnamed: C35.1, R55.2
unnamed: C36.1, R56.2
unnamed: C37.1, R57.2
unnamed: C38.1, R58.2
unnamed: C39.1, R59.2
unnamed: C40.1, R60.2
unnamed: C41.1, R61.2
unnamed: C42.1, C44.1, U7.6 (VCOM)
unnamed: C46.1, R54.1, U7.25 (R_IN1-)
unnamed: C46.2, R55.1, U7.26 (R_IN1+)
unnamed: C47.1, R56.1, U7.27 (L_IN1-)
unnamed: C47.2, R57.1, U7.28 (L_IN1+)
unnamed: C48.1, R58.1, U7.1 (L_IN2+)
unnamed: C48.2, R59.1, U7.2 (L_IN2-)
unnamed: C49.1, R60.1, U7.3 (R_IN2+)
unnamed: C49.2, R61.1, U7.4 (R_IN2-)
unnamed: P6.1, U7.14 (OVF)
unnamed: P7.1, R66.2, U7.22 (PDN)
unnamed: R62.2, R63.1, U7.10 (TDM1)
unnamed: R64.2, R65.1, U7.23 (CKS)
unnamed: R67.2, U7.18 (SDTO1)
unnamed: R68.2, R69.1, U7.9 (DIF)
unnamed: R70.2, R71.1, U7.11 (TDM0)
unnamed: R72.2, R73.1, U7.24 (M/S)
SDATA_IN3: R67.1; also elsewhere on the board
TDM_OUT: U7.12 (TDMIN); also elsewhere on the board

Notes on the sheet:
Input: max. 2.7 Vpp (each channel)

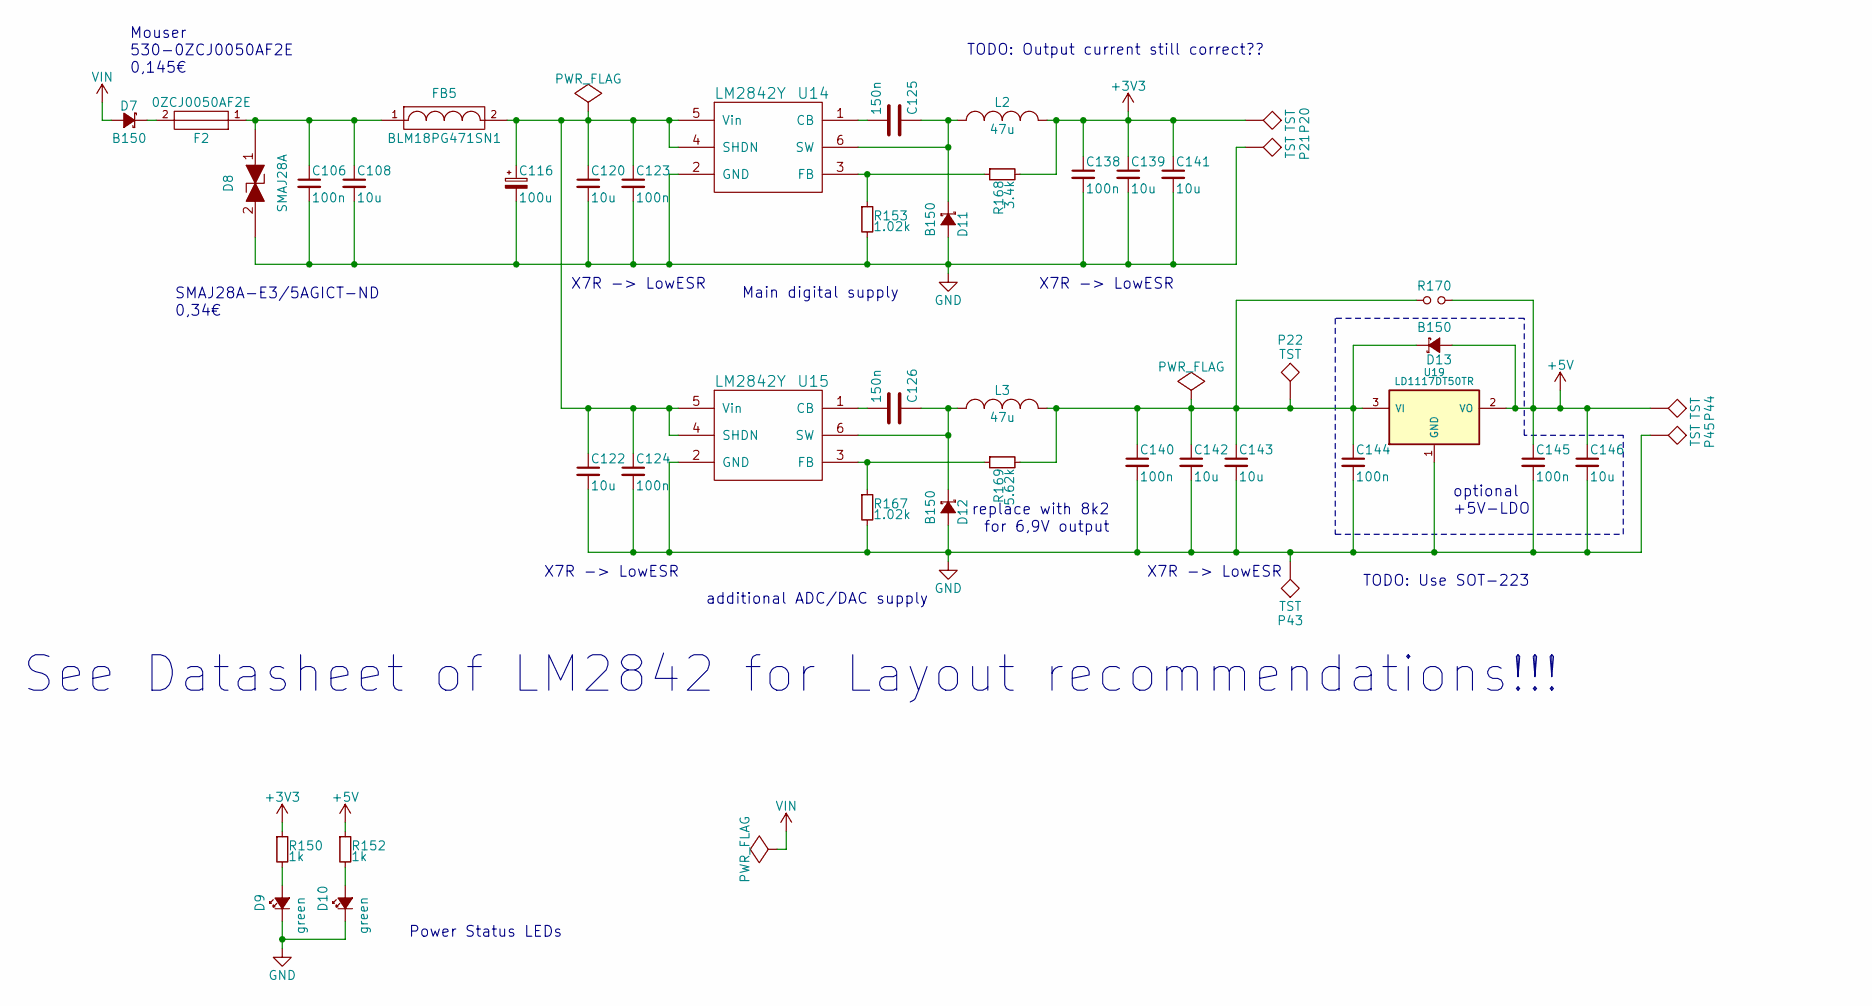
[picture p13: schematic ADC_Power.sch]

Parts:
C106, C123, C124, C138, C140, C144, C145: 100n; C_0603
C108, C120, C122, C139, C141, C142, C143, C146: 10u; C_0805
C116: 100u; CP_Elec_10x10.5
C125, C126: 150n; C_0805
D7, D11, D12, D13: B150; SMA
D8: SMAJ28A; SMA; Digikey_Paro_No SMAJ28A-E3/5AGICT-ND
D9, D10: green; R_0603
F2: 0ZCJ0050AF2E; R_1206; Mouser_Part_No 530-0ZCJ0050AF2E
FB5: BLM18PG471SN1; R_0603; Mouser_Part_No 81-BLM18PG471SN1D
L2, L3: 47u; Choke_SMD_6.0x5.8
P20, P21, P22, P43, P44, P45: TST; Measurement_Point_Round-SMD-Pad_Small
R150, R152: 1k; R_0603
R153, R167: 1.02k; R_0603
R168: 3.4k; R_0603
R169: 5.62k; R_0603
R170: Jumper_NO_Small; R_0603_Solderjumper_Open
U14, U15: LM2842Y; SOT23-6_1.7x3.0mm_Pitch0.95mm
U19: LD1117DT50TR; SOT-223

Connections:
+3V3: C138.1, C139.1, C141.1, L2.2, P20.1, R150.1, R168.2
+5V: C145.1, C146.1, D13.2 (A), P44.1, R152.1, R170.2, U19.2 (VO); also elsewhere on the board
GND: C106.2, C108.2, C116.2, C120.2, C122.2, C123.2, C124.2, C138.2, C139.2, C140.2, C141.2, C142.2, C143.2, C144.2, C145.2, C146.2, D8.2, D9.1 (K), D10.1 (K), D11.2 (A), D12.2 (A), P21.1, P43.1, P45.1, R153.2, R167.2, U14.2 (GND), U15.2 (GND), U19.1 (GND); also elsewhere on the board
unnamed: C106.1, C108.1, D8.1, F2.1, FB5.1
unnamed: C116.1, C120.1, C122.1, C123.1, C124.1, FB5.2, U14.4 (SHDN), U14.5 (Vin), U15.4 (SHDN), U15.5 (Vin)
unnamed: C125.1, D11.1 (K), L2.1, U14.6 (SW)
unnamed: C125.2, U14.1 (CB)
unnamed: C126.1, D12.1 (K), L3.1, U15.6 (SW)
unnamed: C126.2, U15.1 (CB)
unnamed: C140.1, C142.1, C143.1, C144.1, D13.1 (K), L3.2, P22.1, R169.2, R170.1, U19.3 (VI)
unnamed: D7.1 (K), F2.2
unnamed: D9.2 (A), R150.2
unnamed: D10.2 (A), R152.2
unnamed: R153.1, R168.1, U14.3 (FB)
unnamed: R167.1, R169.1, U15.3 (FB)
VIN: D7.2 (A); also elsewhere on the board

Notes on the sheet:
Power Status LEDs
Main digital supply
additional ADC/DAC supply
X7R -> LowESR
See Datasheet of LM2842 for Layout recommendations!!!
replace with 8k2 for 6,9V output
optional +5V-LDO
SMAJ28A-E3/5AGICT-ND 0,34€
Mouser 530-0ZCJ0050AF2E 0,145€
TODO: Use SOT-223
TODO: Output current still correct??

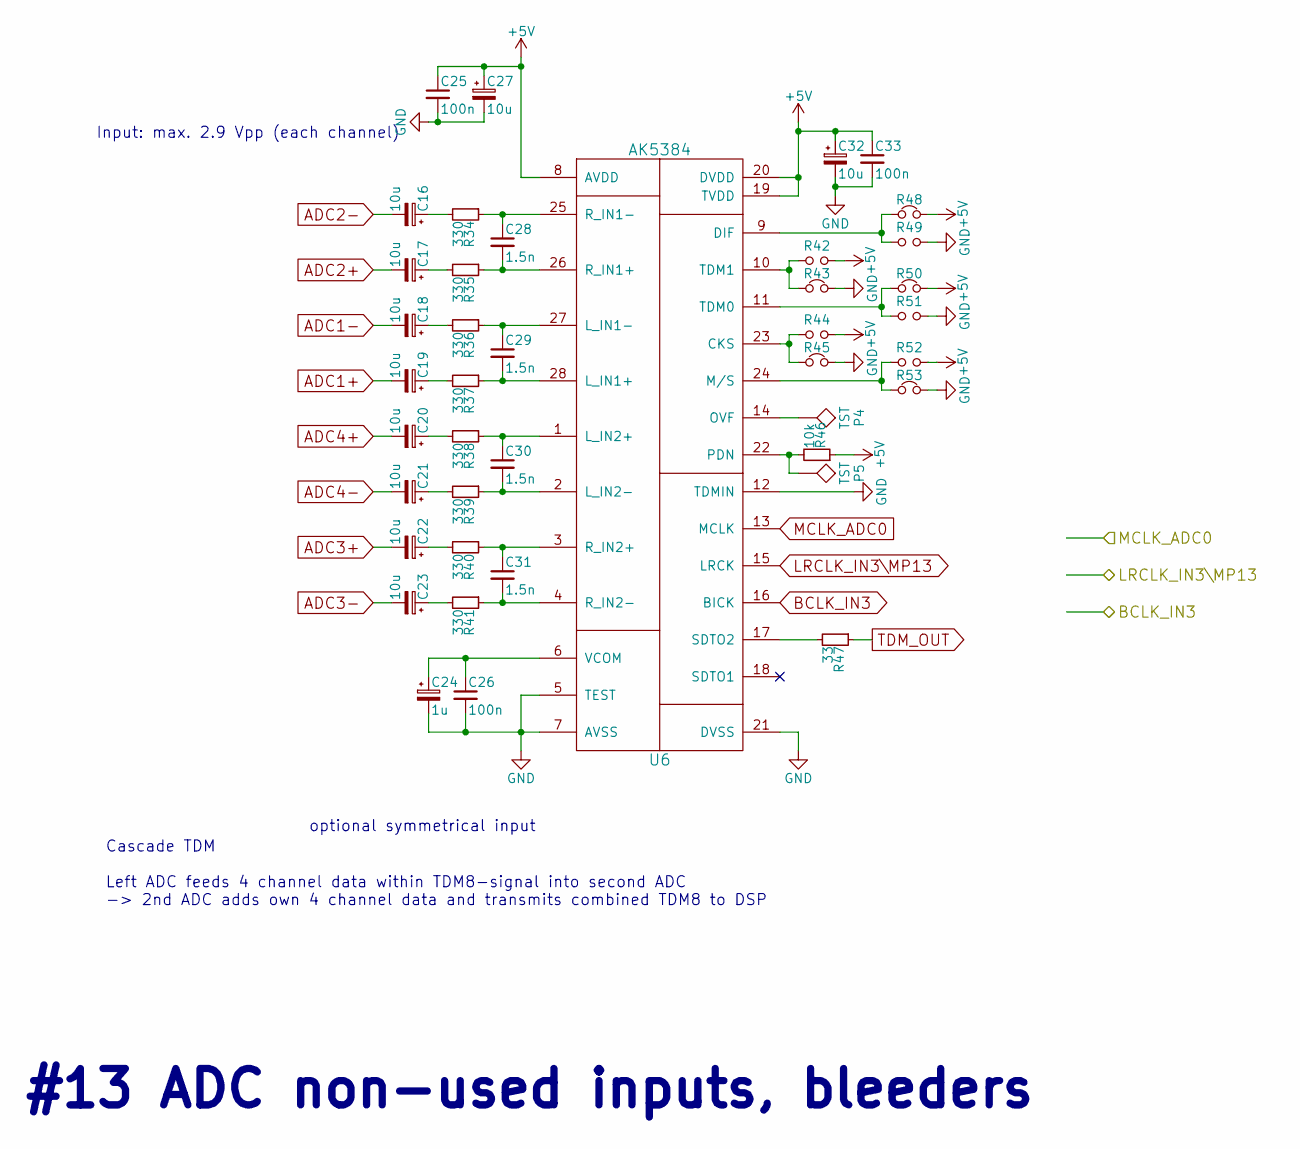
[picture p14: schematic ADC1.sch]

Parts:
C16, C17, C18, C19, C20, C21, C22, C23: 10u; C_Radial_D5_L11_P2.5
C24: 1u; C_0603
C25, C26, C33: 100n; C_0603
C27, C32: 10u; C_0805
C28, C29, C30, C31: 1.5n; C_1206
P4, P5: TST; Measurement_Point_Round-SMD-Pad_Small
R34, R35, R36, R37, R38, R39, R40, R41: 330; R_0603
R42, R44, R49, R51, R52: Jumper_NO_Small; R_0603_Solderjumper_Open
R43, R45, R48, R50, R53: Jumper_NC_Small; R_0603_Solderjumper_Closed
R46: 10k; R_0603
R47: 33; R_0603
U6: AK5384; SSOP-28_5.3x10.2mm_Pitch0.65mm

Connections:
+5V: C25.1, C27.1, C32.1, C33.1, R42.1, R44.1, R46.1, R48.2, R50.1, R52.1, U6.8 (AVDD), U6.19 (TVDD), U6.20 (DVDD); also elsewhere on the board
ADC1+: C19.2; also elsewhere on the board
ADC1-: C18.2; also elsewhere on the board
ADC2+: C17.2; also elsewhere on the board
ADC2-: C16.2; also elsewhere on the board
ADC3+: C22.2; also elsewhere on the board
ADC3-: C23.2; also elsewhere on the board
ADC4+: C20.2; also elsewhere on the board
ADC4-: C21.2; also elsewhere on the board
BCLK_IN3: U6.16 (BICK); also elsewhere on the board
GND: C24.2, C25.2, C26.2, C27.2, C32.2, C33.2, R43.2, R45.2, R49.2, R51.2, R53.2, U6.5 (TEST), U6.7 (AVSS), U6.12 (TDMIN), U6.21 (DVSS); also elsewhere on the board
LRCLK_IN3\MP13: U6.15 (LRCK); also elsewhere on the board
MCLK_ADC0: U6.13 (MCLK); also elsewhere on the board
unnamed: C16.1, R34.2
unnamed: C17.1, R35.2
unnamed: C18.1, R36.2
unnamed: C19.1, R37.2
unnamed: C20.1, R38.2
unnamed: C21.1, R39.2
unnamed: C22.1, R40.2
unnamed: C23.1, R41.2
unnamed: C24.1, C26.1, U6.6 (VCOM)
unnamed: C28.1, R34.1, U6.25 (R_IN1-)
unnamed: C28.2, R35.1, U6.26 (R_IN1+)
unnamed: C29.1, R36.1, U6.27 (L_IN1-)
unnamed: C29.2, R37.1, U6.28 (L_IN1+)
unnamed: C30.1, R38.1, U6.1 (L_IN2+)
unnamed: C30.2, R39.1, U6.2 (L_IN2-)
unnamed: C31.1, R40.1, U6.3 (R_IN2+)
unnamed: C31.2, R41.1, U6.4 (R_IN2-)
unnamed: P4.1, U6.14 (OVF)
unnamed: P5.1, R46.2, U6.22 (PDN)
unnamed: R42.2, R43.1, U6.10 (TDM1)
unnamed: R44.2, R45.1, U6.23 (CKS)
unnamed: R47.2, U6.17 (SDTO2)
unnamed: R48.1, R49.1, U6.9 (DIF)
unnamed: R50.2, R51.1, U6.11 (TDM0)
unnamed: R52.2, R53.1, U6.24 (M/S)
TDM_OUT: R47.1; also elsewhere on the board

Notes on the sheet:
optional symmetrical input
Input: max. 2.9 Vpp (each channel)
Cascade TDM Left ADC feeds 4 channel data within TDM8-signal into second ADC -> 2nd ADC adds own 4 channel data and transmits combined TDM8 to DSP
#13 ADC non-used inputs, bleeders

Board: 2 copper layers, 189 parts (0 on the bottom side), 122 nets, no tracks yet.

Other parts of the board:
P9, P10: STDCONN; IDC_Header_Straight_16pins

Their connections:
BCLK_IN3: P9.7, P10.7; also elsewhere on the board
GND: P9.2, P9.4, P9.6, P9.8, P9.10, P9.12, P9.14, P9.16, P10.2, P10.4, P10.6, P10.8, P10.10, P10.12, P10.14, P10.16; also elsewhere on the board
LRCLK_IN3\MP13: P9.9, P10.9; also elsewhere on the board
MCLK_ADC0: P9.15; also elsewhere on the board
MCLK_ADC1: P10.15; also elsewhere on the board
SDATA_IN3: P10.5; also elsewhere on the board
VIN: P9.1, P10.1; also elsewhere on the board
